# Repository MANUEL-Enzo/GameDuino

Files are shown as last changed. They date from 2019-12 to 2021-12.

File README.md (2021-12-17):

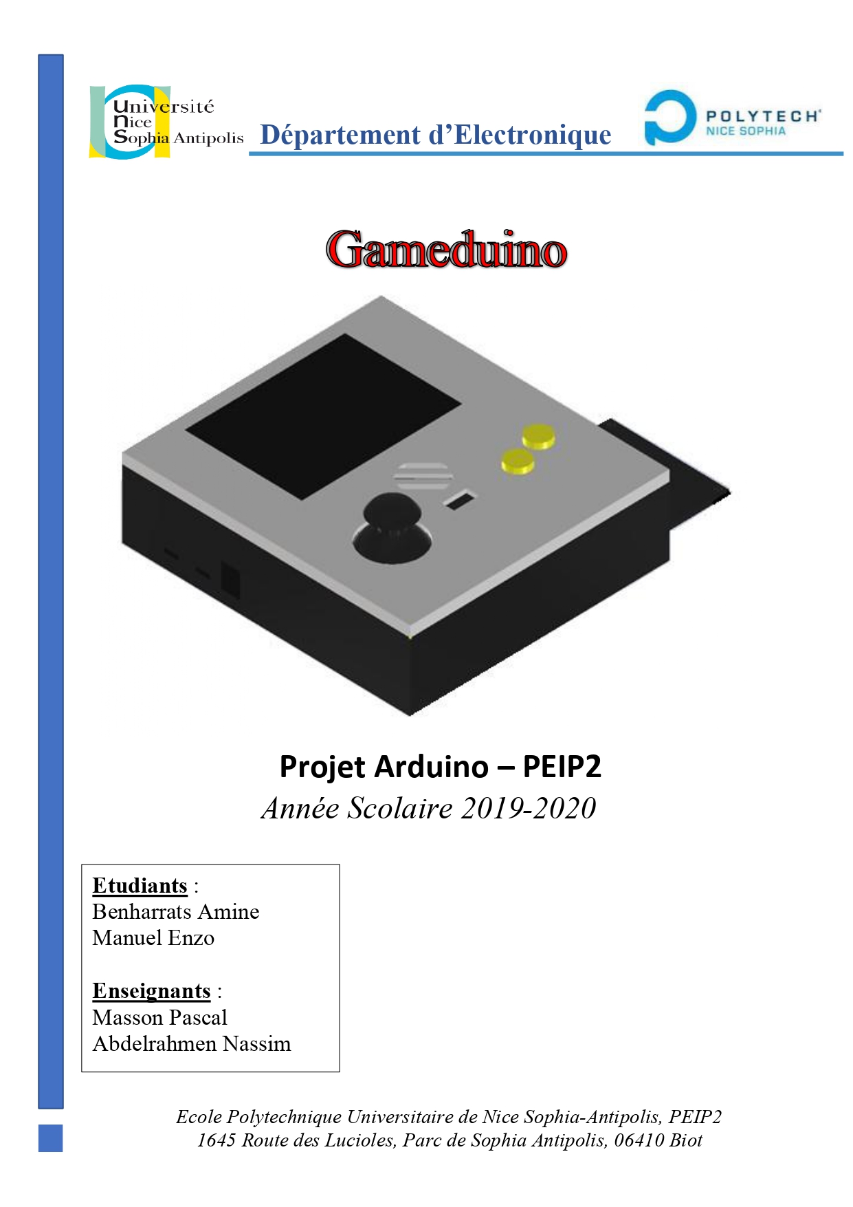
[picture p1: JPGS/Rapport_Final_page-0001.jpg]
Rapport

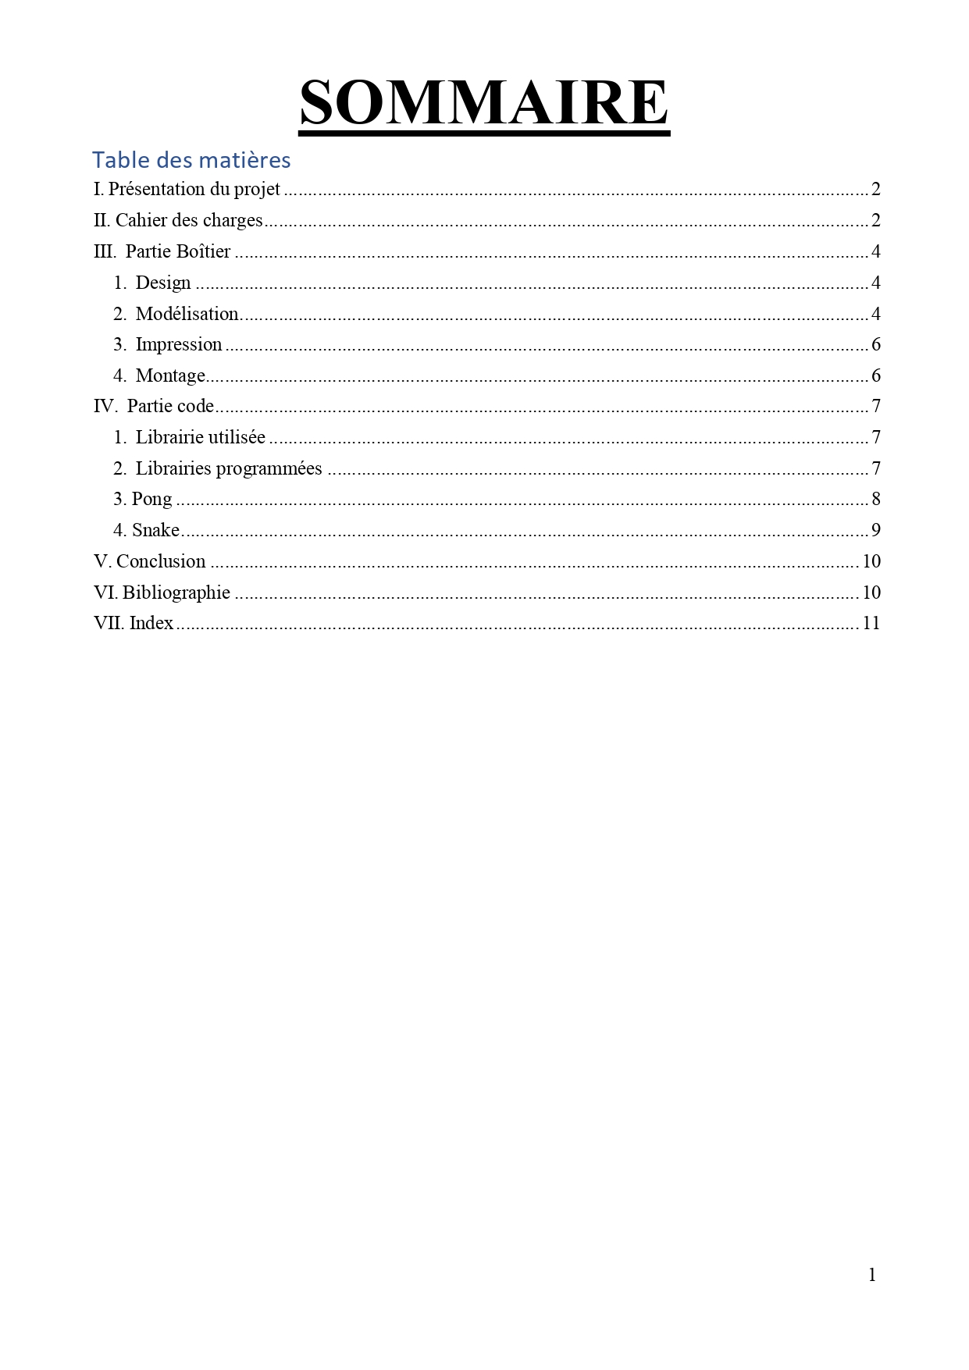
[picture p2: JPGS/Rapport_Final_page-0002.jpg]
Rapport

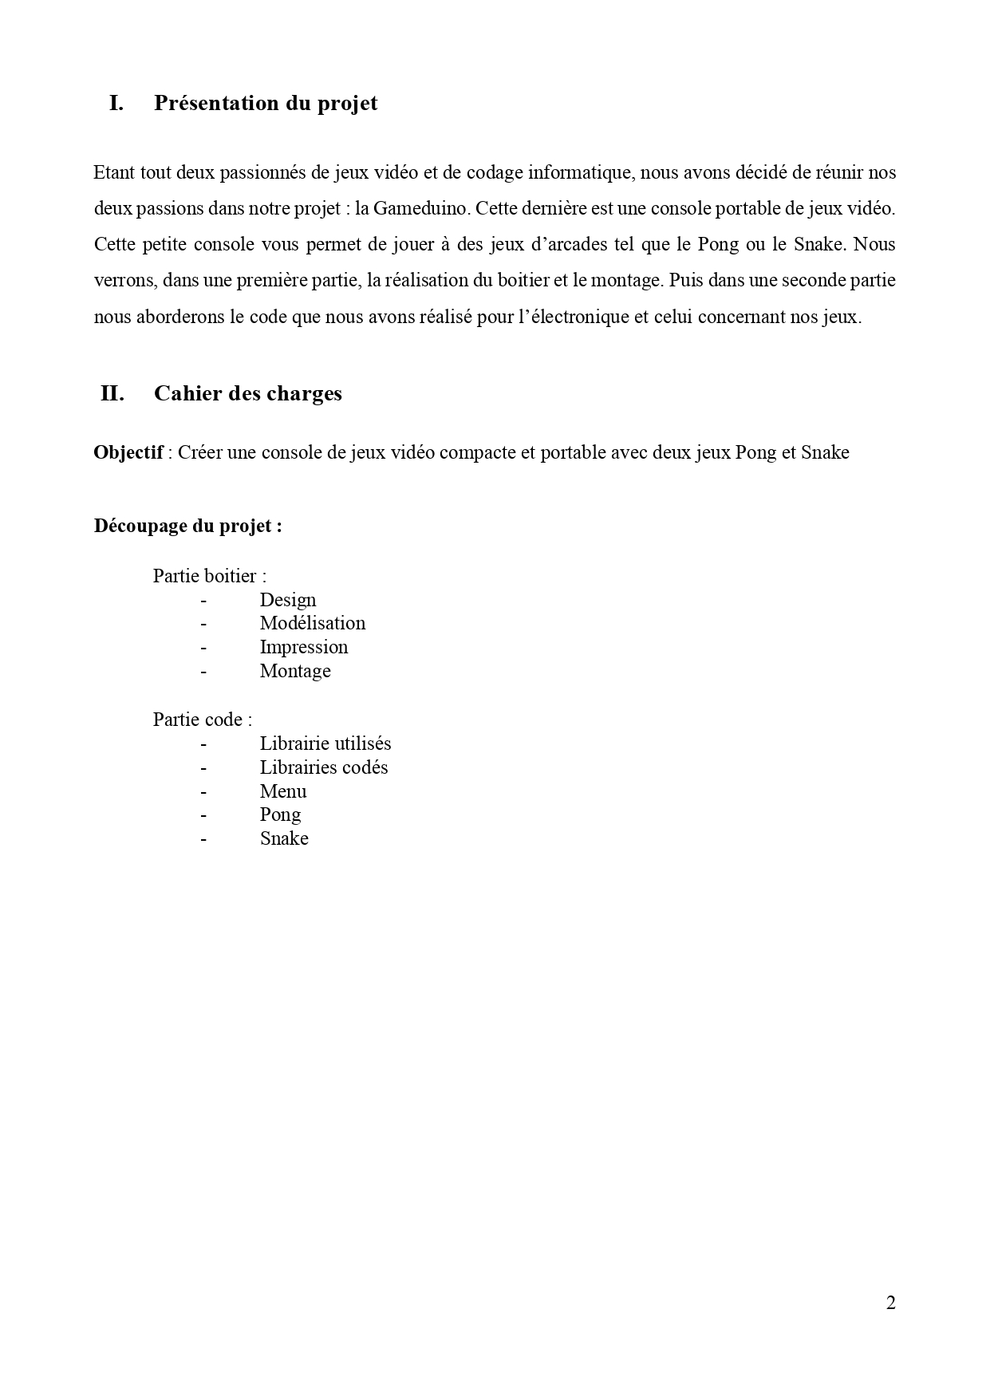
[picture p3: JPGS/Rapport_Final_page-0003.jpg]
Rapport

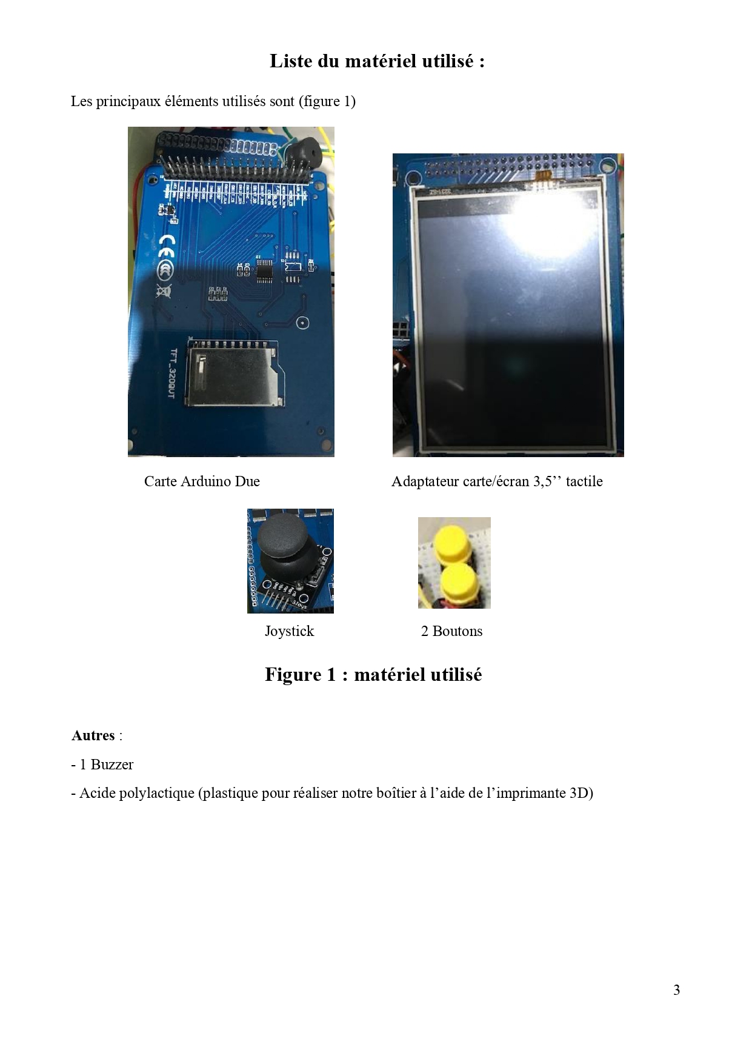
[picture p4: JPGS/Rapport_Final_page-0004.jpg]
Rapport

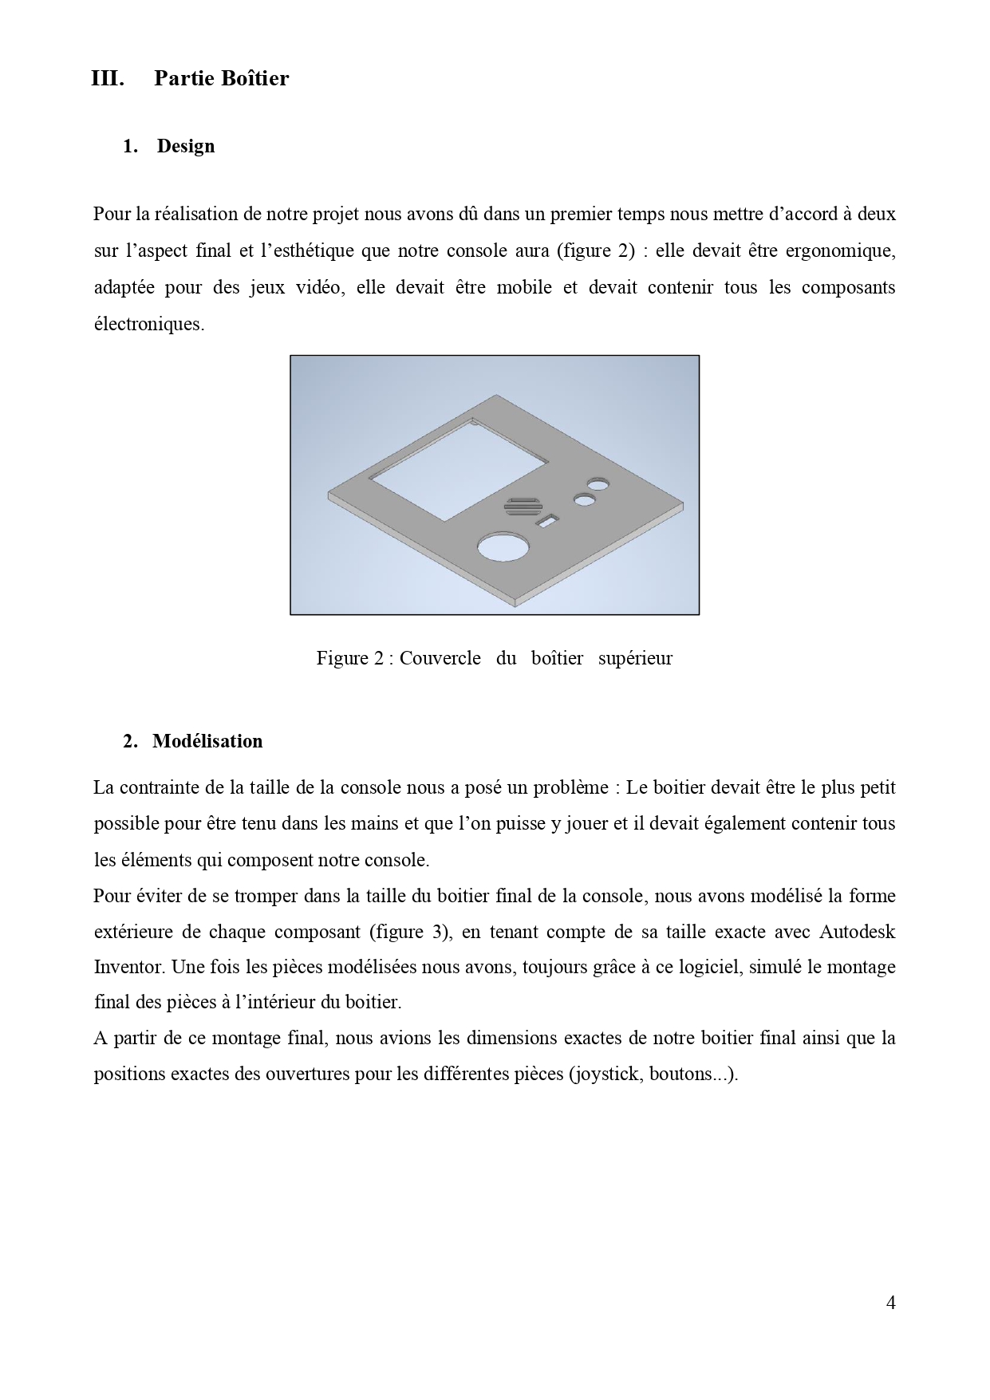
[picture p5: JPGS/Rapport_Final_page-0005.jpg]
Rapport

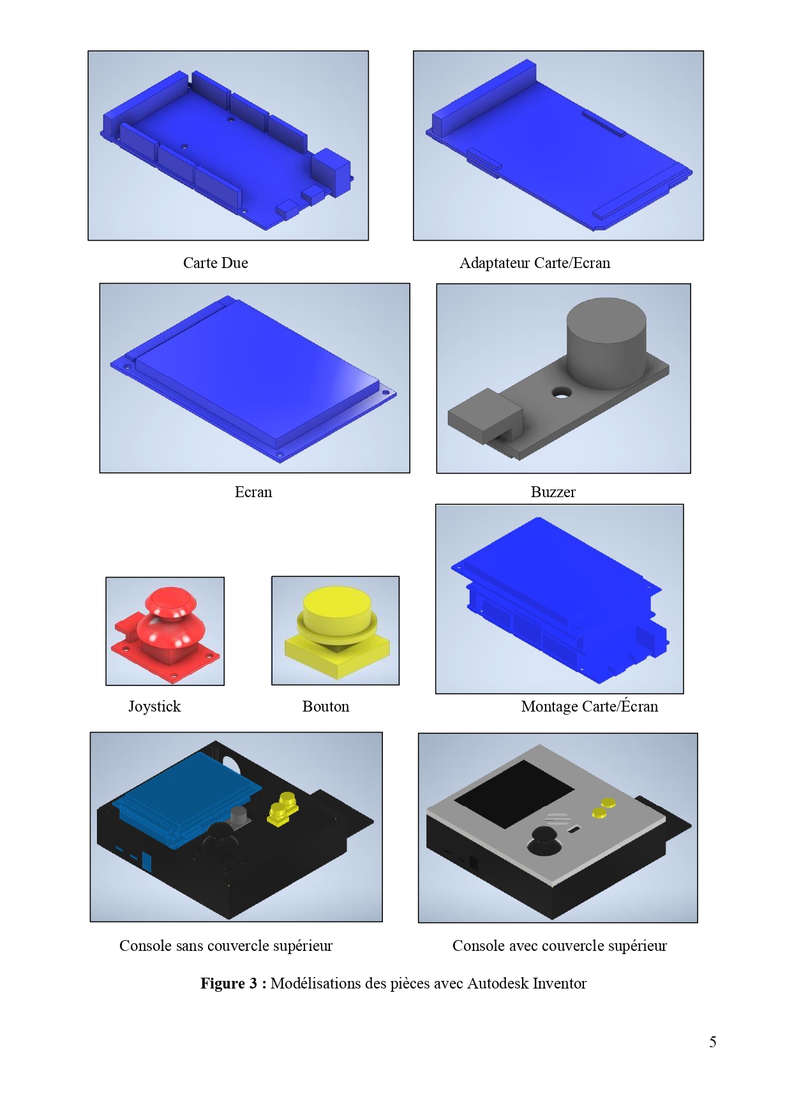
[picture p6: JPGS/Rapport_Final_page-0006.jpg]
Rapport

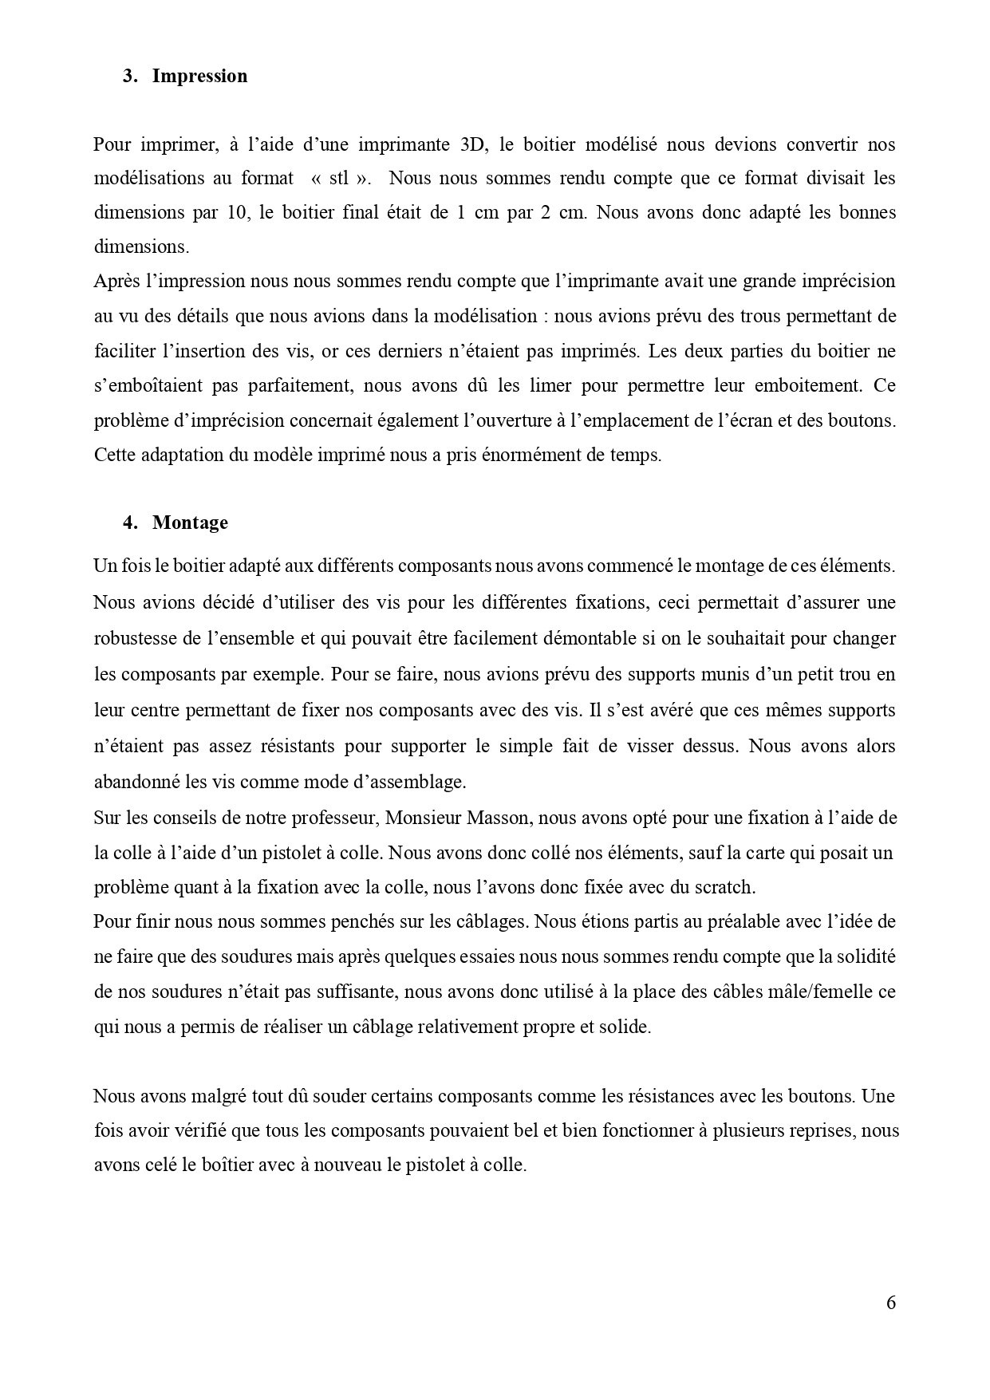
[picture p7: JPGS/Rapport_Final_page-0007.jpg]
Rapport

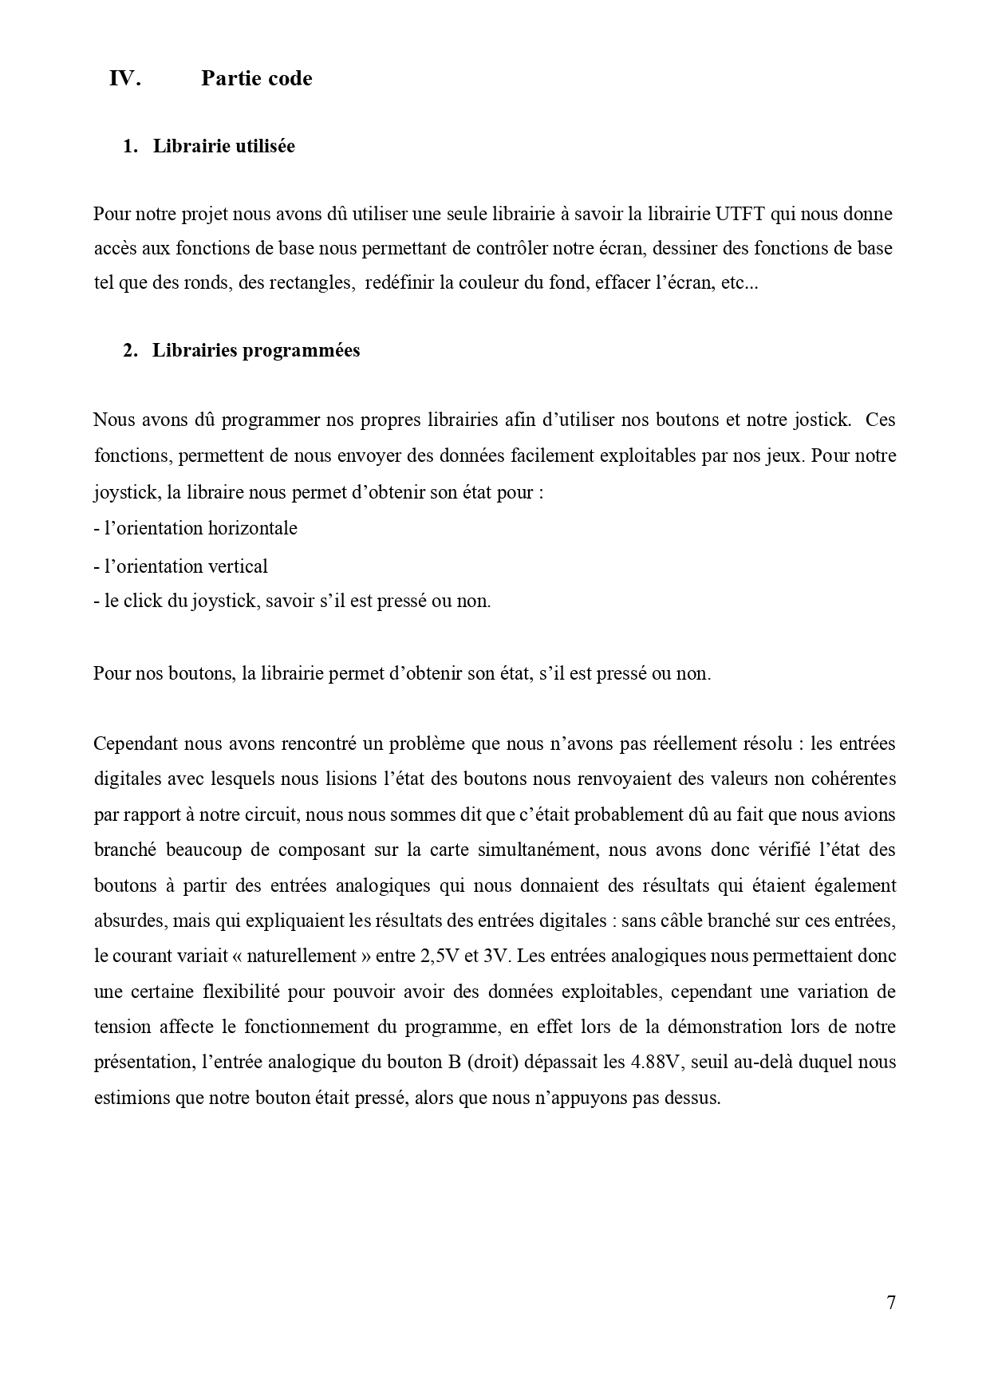
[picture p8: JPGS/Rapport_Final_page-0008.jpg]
Rapport

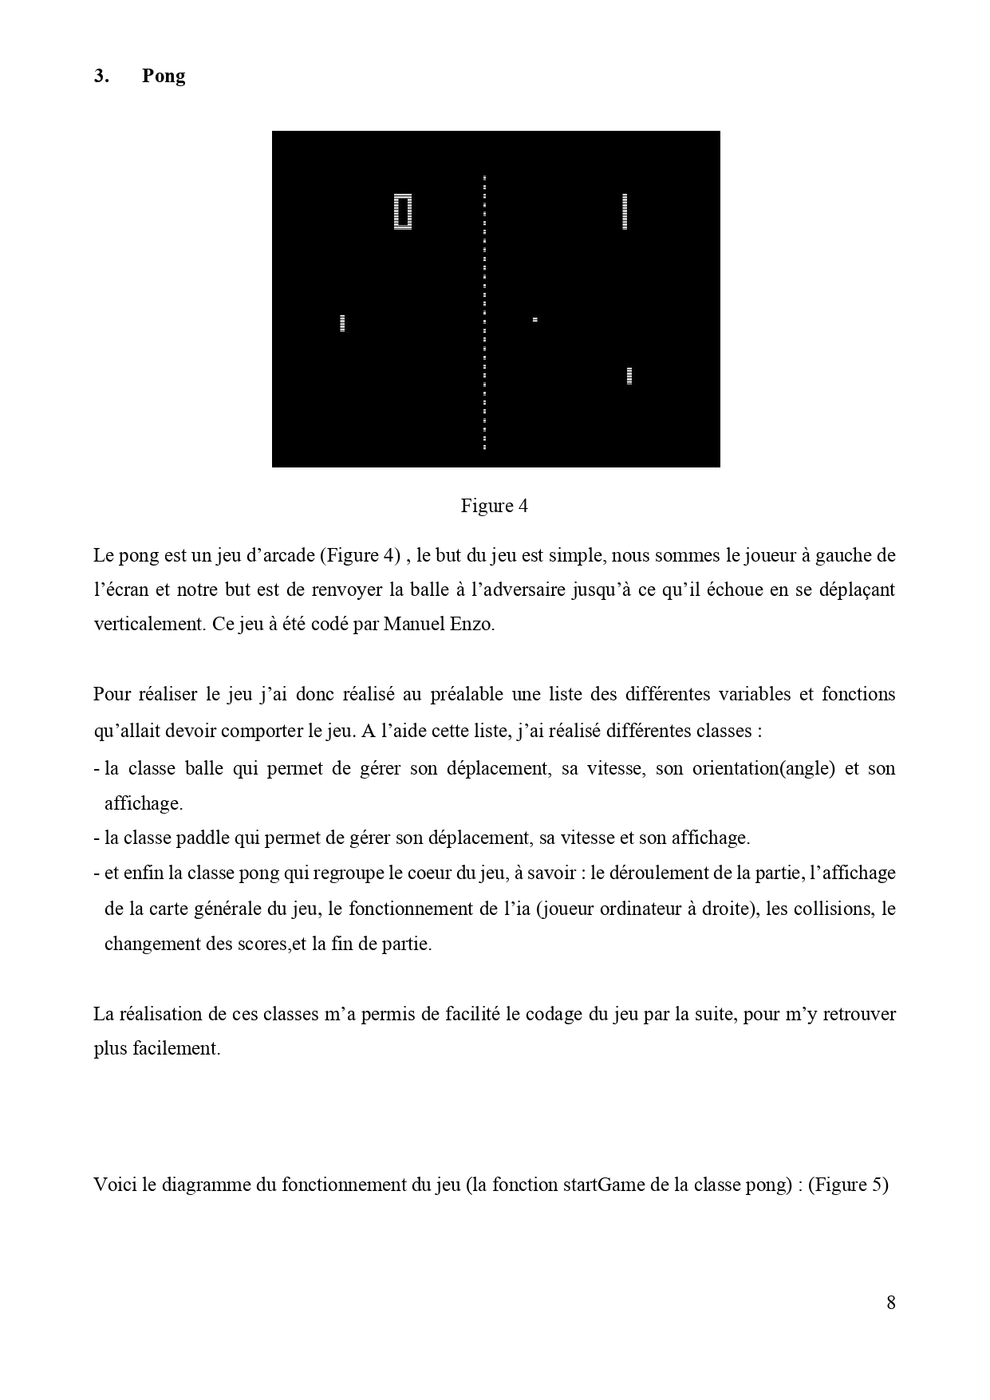
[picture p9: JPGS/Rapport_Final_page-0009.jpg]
Rapport

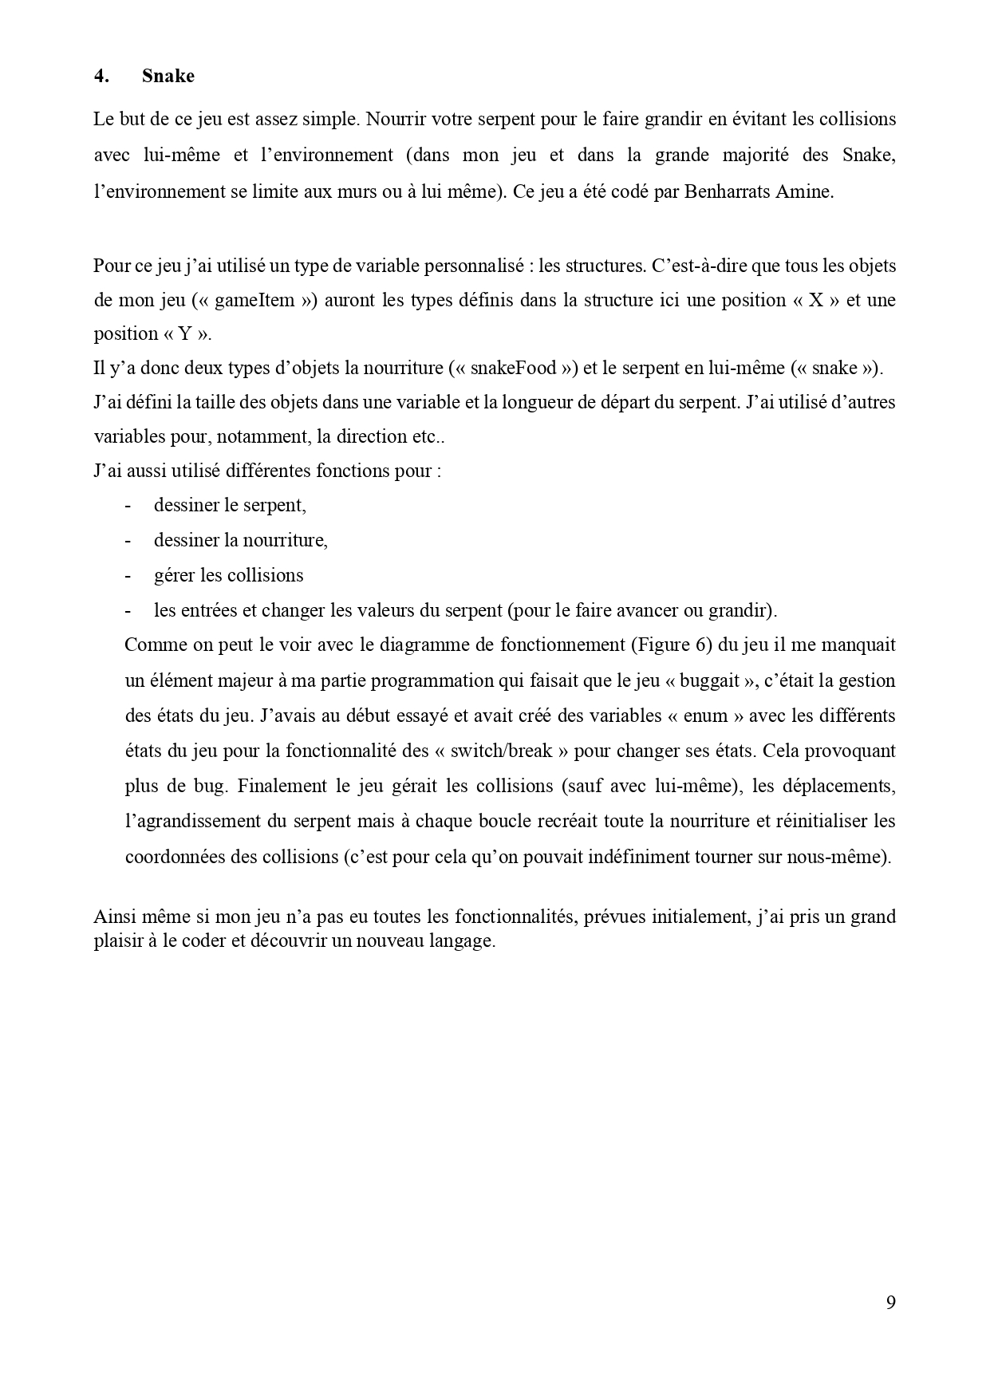
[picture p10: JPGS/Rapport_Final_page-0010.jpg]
Rapport

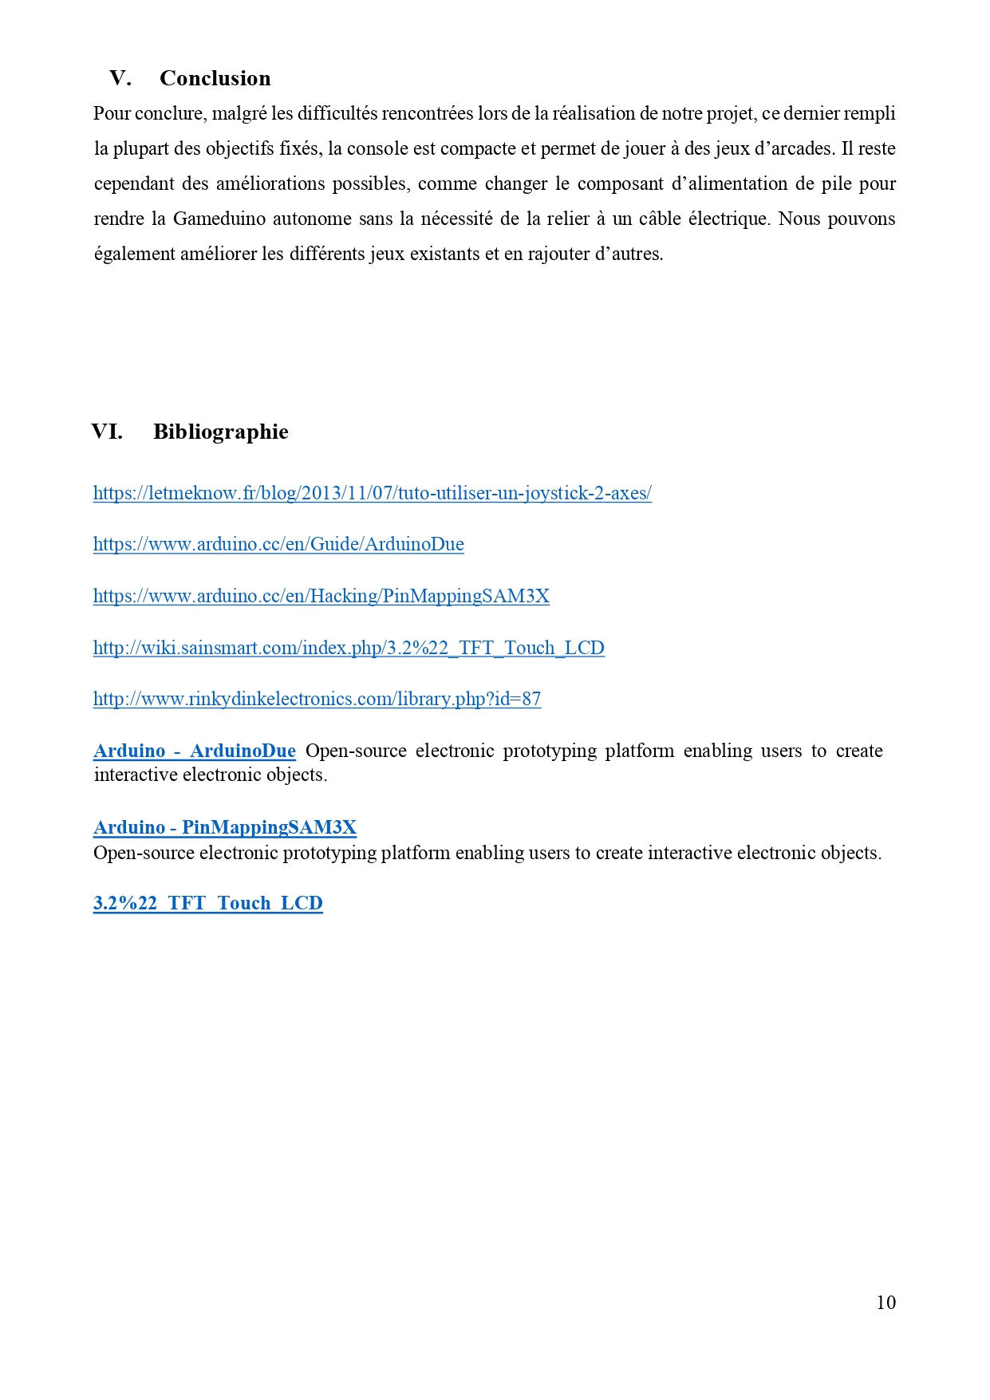
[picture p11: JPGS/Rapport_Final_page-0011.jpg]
Rapport

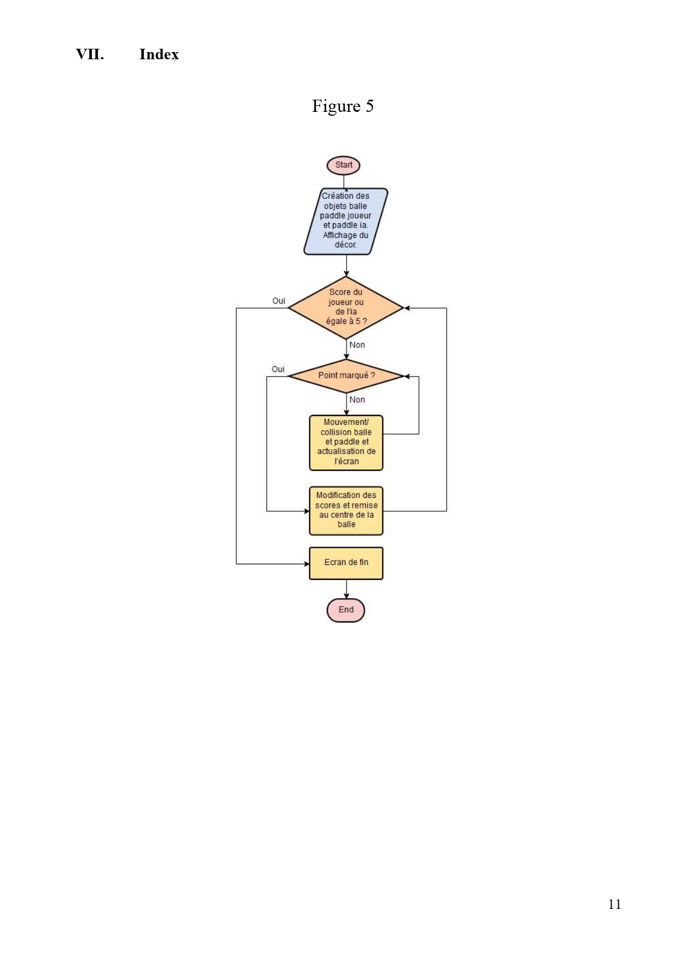
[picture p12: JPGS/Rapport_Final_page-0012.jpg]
Rapport

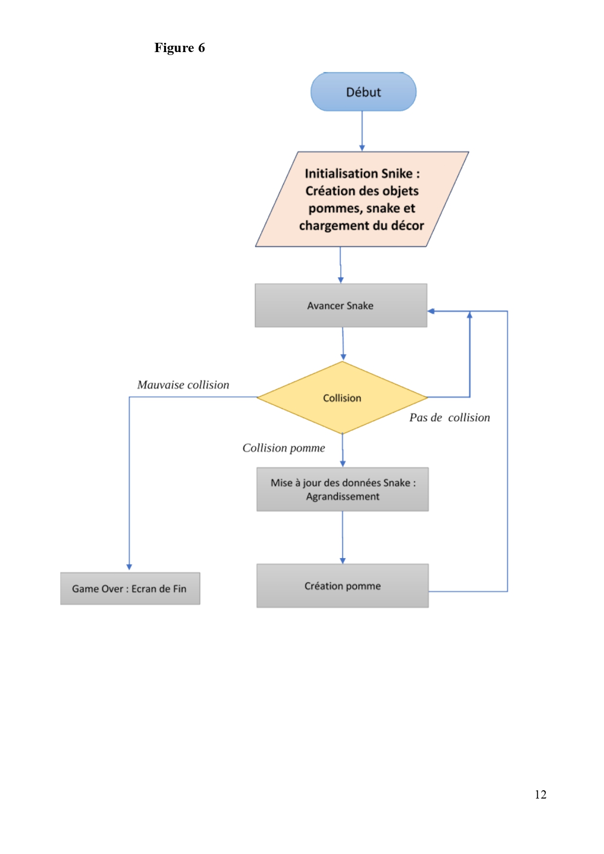
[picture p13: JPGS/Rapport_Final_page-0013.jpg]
Rapport


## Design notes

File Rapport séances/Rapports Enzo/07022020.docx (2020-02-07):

Compte-rendu du 07/02/2020:

- J’ai fini la modélisation du boitier : j’ai fait une place pour la pile et l’interrupteur ON/OFF. J’ai fait les fixations pour le joystick ainsi que le buzzer, et j’ai mis le fond du boitier à niveau pour pouvoir coller les boutons à la bonne hauteur.

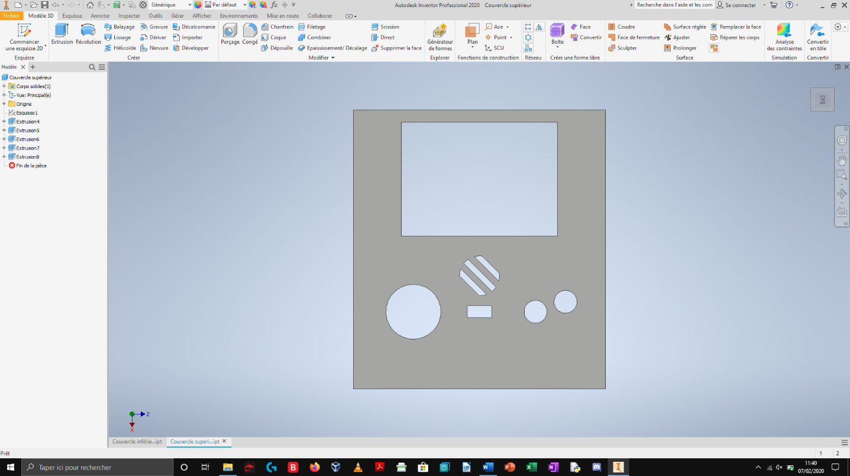
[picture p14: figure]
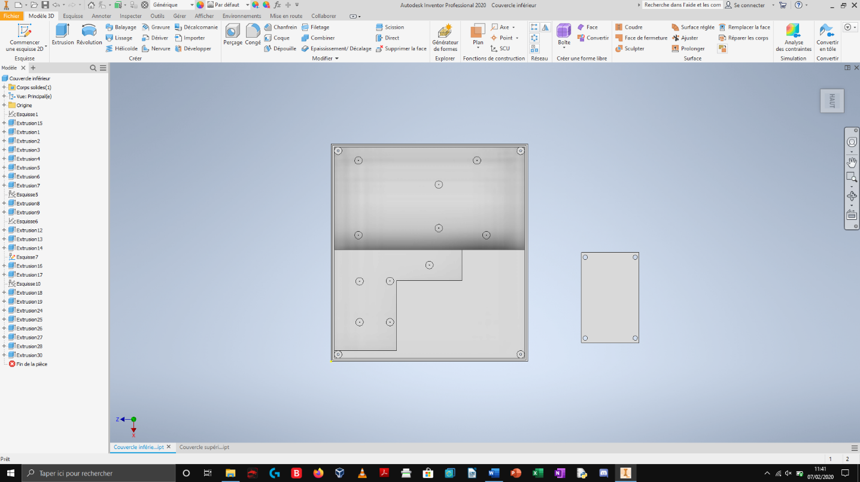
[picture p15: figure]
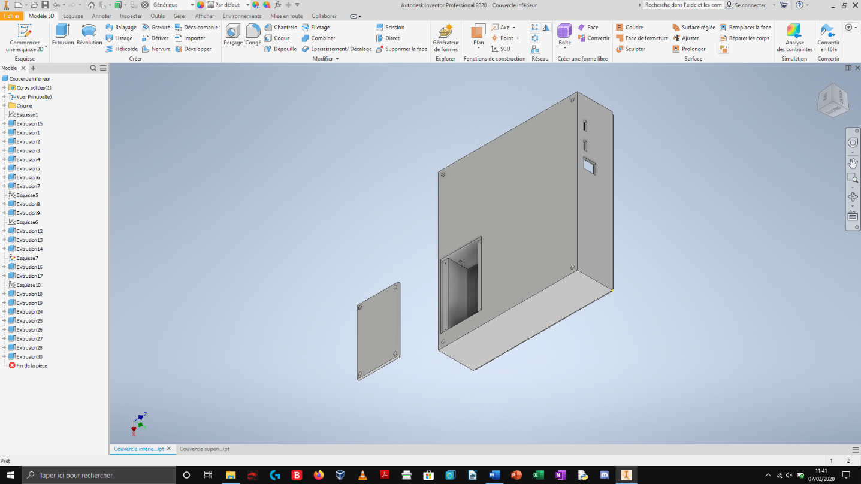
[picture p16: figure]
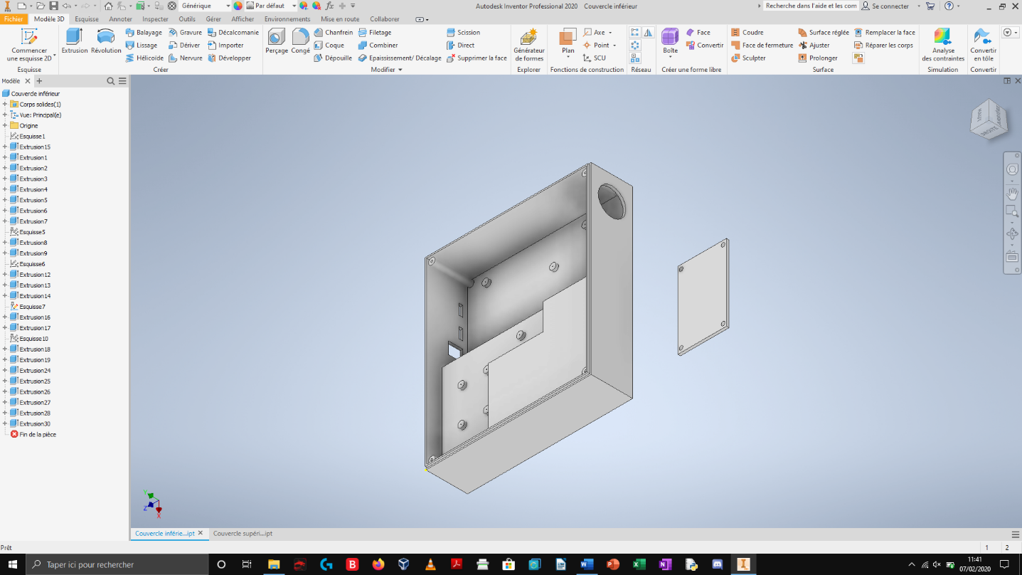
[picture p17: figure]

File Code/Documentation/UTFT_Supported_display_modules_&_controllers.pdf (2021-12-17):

http://www.RinkyDinkElectronics.com/ | (C)2018 Rinky-Dink Electronics, Henning Karlsen

# UTFT

# Multi-Platform Universal TFT display library

# Supported display modules & TFT Controllers

These display modules have been tested, and works with the UTFT library. Please note that vendors/manufacturers may have changed the display modules since I got my test module so there are no guarantees. It should also be noted that not all displays have been tested on all development boards. Compatibility with development boards is tested

with a random selection of displays.

## Other modules may work as long as they have one of the supported controllers (see the

section marked important above).

## The displays marked as shields below have only been tested on platforms where they plug directly in (i.e. on standard “Arduino” form factor development boards.)

Supplier: | ITead Studio
Website: | http://imall.iteadstudio.com/
Module | Model for UTFT() | Controller | Notes | Module | Shield
ITDB02-1.8SP | ITDB18SP | ST7735 | |
ITDB02-2.2 | ITDB22 | HX8340-B(T) | |
ITDB02-2.4E | ITDB24E_8 | S6D1121 | 8bit mode |
ITDB02-2.4E | ITDB24E_16 | S6D1121 | 16bit mode |
ITDB02-2.4E V2 | ITDB24E_V2_8 | ILI9341 | 8bit mode |
ITDB02-2.4E V2 | ITDB24E_V2_16 | ILI9341 | 16bit mode |
2.4” Touch Shield V2 | ITDB24E_V2_8 | ILI9341 | Only tested on Arduino Uno | |
ITDB02-2.8 | ITDB28 | ILI9325D | 8bit version only |
ITDB02-2.8 V2 | ITDB28_V2 / ITDB28_V2_ALT | ILI9341 | See footnote¹ |
2.8” Touch Shield V2 | ITDB28_V2 | ILI9341 | Only tested on Arduino Uno | |
ITDB02-3.2S | ITDB32S | SSD1289 | |
ITDB02-3.2S V2 | ITDB32S_V2 | ILI9341 | |
ITDB02-3.2WD | ITDB32WD | HX8352-A | |
3.2” Touch Shield V2 | ITDB32S_V2 | ILI9341 | Only tested on Arduino Mega/Due | |
ITDB02-4.3 | ITDB43 | SSD1963 | |
ITDB02-5.0 | ITDB50 | SSD1963 | |
ITDB02-2.2SP | ITDB22SP | HX8340-B(N) | Retired |
ITDB02-2.4 | ITDB24 | ILI9325C | Retired |
ITDB02-2.4D | ITDB24D | ILI9325D | Retired |
ITDB02-2.4DWOT | ITDB24DWOT | ILI9325D | Retired |
ITDB02-2.5H | ITDB25H | S1D19122 | Retired |
ITDB02-3.2 | ITDB32 | HX8347-A | Retired |
ITDB02-3.2WC | ITDB32WC | ILI9327 | Retired |
Supplier: | NKC Electronics
Website: | http://store.nkcelectronics.com/
Module | Model for UTFT() | Controller | Notes | Module | Shield
RGB LCD 65K color module | LPH9135 | PCF8833 | | |
Supplier: | Electronics Lee
Website: | http://stores.ebay.com/electronics-lee
Module | Model for UTFT() | Controller | Notes | Module | Shield
3.2” TFT LCD Arduino Shield - Revision A | ELEE32_REVA² | SSD1289 | Uses 16bit latched mode³ Not supported on chipKit or Arduino Due | |
Shield - Revision B 3.2” TFT LCD Arduino | ELEE32_REVB | SSD1289 | 8bit mode⁴ Not supported on chipKit or Arduino Due | |

1 It seems like some modules are 16bit even though they are marked as 8bit. Use ITDB28_V2_ALT for those modules. 2 Changed from INFINIT32 3 Use UTFT myGLCD(ELEE32_REVA,A1,A2,A0,A3,A5); to initialize 4 Use UTFT myGLCD(ELEE32_REVB,A1,A2,A0,99); to initialize

# IMPORTANT:

## Please note that any attempt to use this library with display modules that are not on this list is done at your own risk. Using this library with display modules not on this list may work just fine, but there is also a tiny, tiny risk that it may damage

your display module and/or development board. Consider yourself warned.

## Do not ask me if a display module that is not on this list will work with the library. As I have not tested it I simply do not know. You will just have to try for

yourself (at your own risk).

## If your exact display module/shield is not on this list, or you have bought it from another vendor than the one listed as the supplier, you will have to direct any

questions to your vendor. I cannot answer them.

## There is also no point in sending me code that will make display modules/shields not on this list work with the library. I only add support for new display modules and

shields at the request from vendors and manufacturers.

Supplier: | Coldtears Electronics
Website: | http://stores.ebay.com/coldtears-electronics-store
Module | Model for UTFT() | Controller | Notes | Module | Shield
2.2" TFT LCD Module | CTE22 | S6D0164 | Basic support only⁵ |
2.8" TFT LCD Module | CTE28 | ILI9325D | Basic support only⁵ |
3.2" TFT LCD Module (R2) | CTE32_R2 | ILI9341 | Basic support only⁵ |
3.2" HR TFT LCD Module | CTE32HR | ILI9481 | Basic support only⁵ |
3.2" Wide TFT LCD Module | CTE32W | HX8352-A | Basic support only⁵ |
3.5” IPS TFT LCD Module | CTE35IPS | R61581 | Basic support only⁵ |
4.0” TFT LCD Module | CTE40 | ILI9486 | Basic support only⁵ |
5.0" TFT LCD Module | CTE50 | SSD1963 | Basic support only⁵ |
5.0" CPLD TFT LCD Module | CTE50CPLD | CPLD⁶ | |
7.0" TFT LCD Module | CTE70 | SSD1963 | Basic support only⁵ |
7.0" CPLD TFT LCD Module | CTE70CPLD | CPLD⁶ | |
3.2" TFT LCD Module | CTE32 | SSD1289 | Retired |
Supplier: | Watterott electronic
Website: | http://www.watterott.com/
Module | Model for UTFT() | Controller | Notes | Module | Shield
MI0283QT-9A | MI0283QT9 | ILI9341 | Only tested on Arduino Uno |
Supplier: | ElecHouse
Website: | http://www.elechouse.com/
Module | Model for UTFT() | Controller | Notes | Module | Shield
5.0" TFT LCD Module | EHOUSE50 | SSD1963 | |
5.0" CPLD TFT LCD Module | EHOUSE50CPLD | CPLD⁶ | |
7.0" TFT LCD Module | EHOUSE70 | SSD1963 | |
Supplier: | DisplayModule
Website: | http://www.displaymodule.com/
Module | Model for UTFT() | Controller | Notes | Module | Shield
DM-TFT18-101 | DMTFT18101 | HX8353C | |
DM-TFT22-102 | DMTFT22102 | S6D0164 | |
DM-TFT24-104 | DMTFT24104 | ILI9325D | |
DM-TFT28-103 | DMTFT28103 | ILI9325D | |
DM-TFT28-105 | DMTFT28105 | ILI9341 | Incompatible with chipKit | |

5 UTFT does not make use of the on-board Font and Icon Flash chip. 6 CPLD modules are currently not compatible with chipKit.

## If you are unsure which module you have you can try these model codes for the supported controllers instead:

Controller | Model for UTFT() | Supported mode
8bit | 16bit | Serial
CPLD | CPLD | |
HX8340-B(T) | HX8340B_8 |
HX8352-A | HX8352A | |
HX8353-C | HX8353C |
ILI9325D | ILI9325D_8 |
| ILI9325D_16 | |
| ILI9325D_16ALT⁷ | |
ILI9341 | ILI9341_S4P⁸ | | |
| ILI9341_S5P⁹ | | |
| ILI9341_8 |
| ILI9341_16 | |
ILI9481 | ILI9481 | |
ILI9486 | ILI9486 | |
PCF8833 | PCF8833 | | |
R61581 | R61581 | |
S6D0164 | S6D0164 |
S6D1121 | S6D1121_8 |
| S6D1121_16 | |
SSD1289 | SSD1289 | |
| SSD1289_8 |
| SSD1289LATCHED¹⁰ | | LATCHED
SSD1963 | SSD1963_480 | |
| SSD1963_800 | |
| SSD1963_800ALT¹¹ | |
ST7735 | ST7735 | | |

## The following TFT controllers are used by display modules and shields that have been retired. They are still supported but support may be removed in future versions of the library. These controllers are disabled by default to save flash memory. To use them

you must enable support for them in “memorysaver.h”.
Controller | Model for UTFT() | Supported mode
8bit | 16bit | Serial
HX8340-B(N) | HX8340B_S | | |
HX8347-A | HX8347A | |
ILI9325C | ILI9325C |
ILI9327 | ILI9327 | |
S1D19122 | S1D19122 | |

7 Alternative initialization for some 2.8” display modules 8 Use this for 4 Pin serial modules 9 Use this for 5 Pin serial modules 10 Currently only supported on 5v Arduino board, and not on chipKit or Arduino Due 11 Alternative initialization for 7” displays

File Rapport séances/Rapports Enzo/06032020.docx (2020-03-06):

Compte-rendu du 06/03/2020;

Nous avons dans un premier temps essayer de souder nos câbles à nos boutons, buzzer et notre joystick, puis nous avons opté pour des câbles male-femelle. Nous avons soudé nos résistances à nos boutons pour réaliser le circuit nécessaire au fonctionnement de nos boutons. Nous avons collé la carte au fond du boitier, puis l’écran sur le couvercle supérieur, ainsi que le joystick, les boutons et le buzzer dans le boitier inférieur.

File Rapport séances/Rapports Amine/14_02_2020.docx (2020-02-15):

Rapport de séance 14/02/2020

Cette séance nous avons reçu l’impression de la base de notre gameboy et son « couvercle ». Mais l’impression n’était pas parfaite il a donc fallu trouver des solutions.

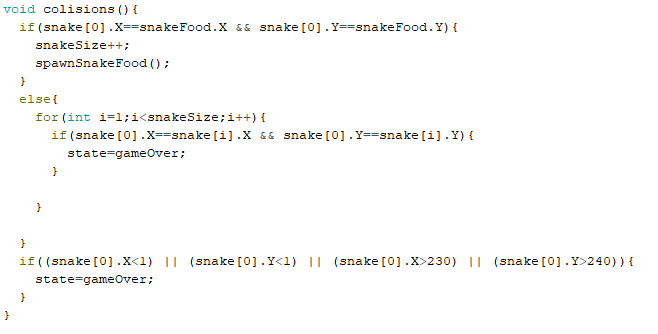
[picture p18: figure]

J’ai cherché quelque solution, mais je me suis quand même plus concentré sur mon code où j’ai fini le système de collision que j’avais commencé à la dernière séance. Ce qui m’a pris le plus de temps est comment « augmenter » la taille du serpent à chaque fois qu’il mange un boost.

Il faut aussi que je règle un problème d’affichage sur notre écran lors du lancement du jeu*

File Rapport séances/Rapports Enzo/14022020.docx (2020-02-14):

Compte rendu : 14/02/2020

J’ai passé ma séance à ajuster l’impression du boitier avec les pièces pour qu’elles rentrent correctement. J’ai compris également que la solution de visser les éléments n’était pas la bonne, je vais donc les coller directement au boitier. Cependant on va réimprimer le couvercle supérieur, car il manque environ 1 mm de matière en hauteur ce que fait que les mesures ne sont pas correctement respectées.

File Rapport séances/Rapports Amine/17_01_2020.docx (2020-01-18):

Rapport du 17/01/2020

Lors de la dernière séance, j’avais avancé sur mon code plus précisément la liste de toute les méthodes et variables dont j’aurais besoin. Mais je me suis vite aperçu que Notepad++ était, certes un bon éditeur de code, mais rien qu’avec mes premières librairies la gestion et l’organisation du projet étaient chaotique. Ainsi, lors de cette séance nous avons chercher un logiciel permettant une meilleure gestion du projet (et de nos codes surtout pour le long termes). Ayant déjà installer Eclipse pour nos cours de Java, on s’est aperçu qu’il existait aussi un package pour le développement en c++, et Eclipse nous proposait même la création d’un projet Arduino. Ainsi lorsque l’on crée une nouvelle classe, l’éditeur crée automatiquement les fichiers « .h » et « .cpp » ce qui nous facilité la tâche et nous permettait un gain de temps mais il nous montré aussi toute les classes déjà crée, leurs relations, leurs affections etc…

Par la suite nous avons finit l’assemblage de nos pièces pour la modélisation de la gameduino.

Par la suite il a fallu présenter notre projet à nos professeurs, ce qui m’a permis de comprendre que nous étions un peu en retard au niveau du code, j’ai donc opté pour une nouvelle stratégie. Au lieu de m’attaquer directement sur le jeu le plus « dur » niveau code, je vais d’abord faire le jeu snake, pour d’une part bien comprendre la gestion de collision, des listes et de la mémoire en c/c++ sur un jeu plus simple, mais aussi pour avoir un rendu plus avancé (voir même fini) pour la journée porte ouverte qui aura lieu le 6 février et la base du code au niveau de la collision pour le jeu pacman. Ainsi le reste de la séance j’ai rétabli la liste des variables et méthode dont j’ai besoin et avancé sur le code.

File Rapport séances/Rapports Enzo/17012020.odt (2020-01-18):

Rapport 17/01/2020

- Nous avons rechercher et télécharger un logiciel permettant de créer des projets en C++ plus facilement : « Eclipse IDE for C/C++ Developers ». Ce logiciel créer automatiquement les fichiers «*.h » et « *.cpp » lorsque l’on veut rajouter une classe et commencer l’écriture des classes nous faisais gagner un temps considérable.

- Nous avons terminé la modélisation de la gameboy et avons donc un aperçu :

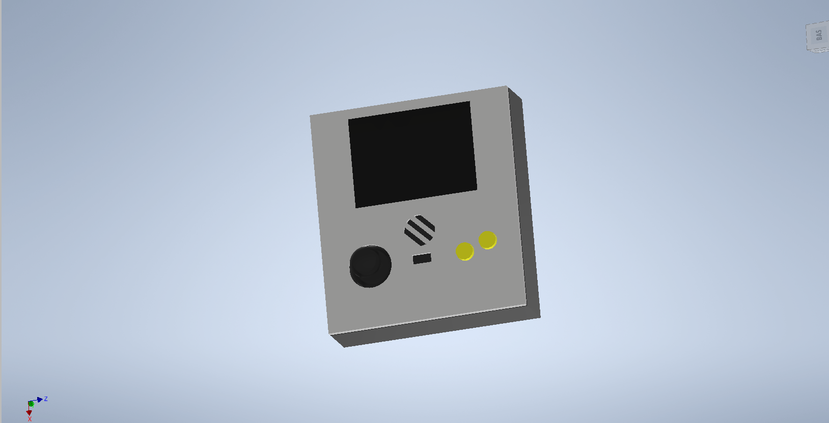
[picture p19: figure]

- Nous avons présenter notre projet à nos professeurs.

- Nous avons commencer à coder les différentes classes de notre jeux. J’ai commencer à rencontrer quelques problèmes concernant le code : comment importer des librairies « élémentaires » pour les calculs de racines ou encore pour choisir un nombre aléatoirement.

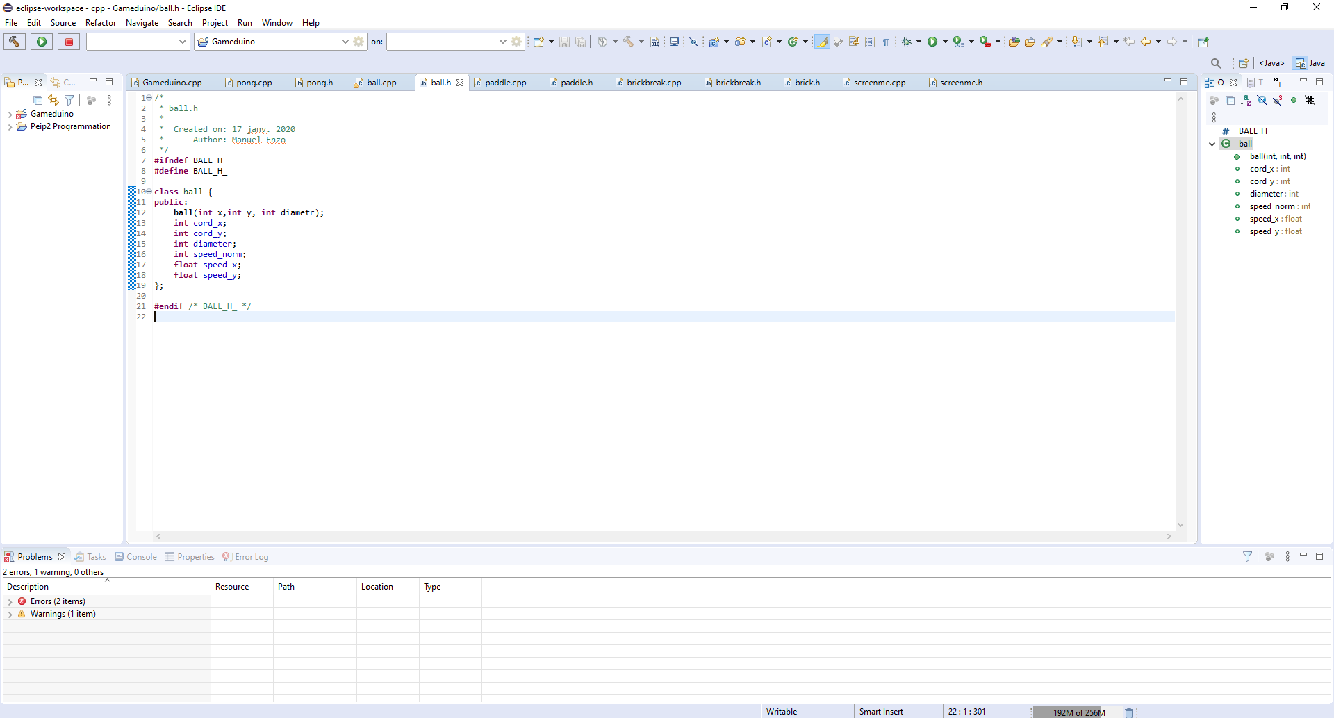
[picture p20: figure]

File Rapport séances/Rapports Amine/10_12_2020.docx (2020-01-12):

Rapport de séance 10/01/2020

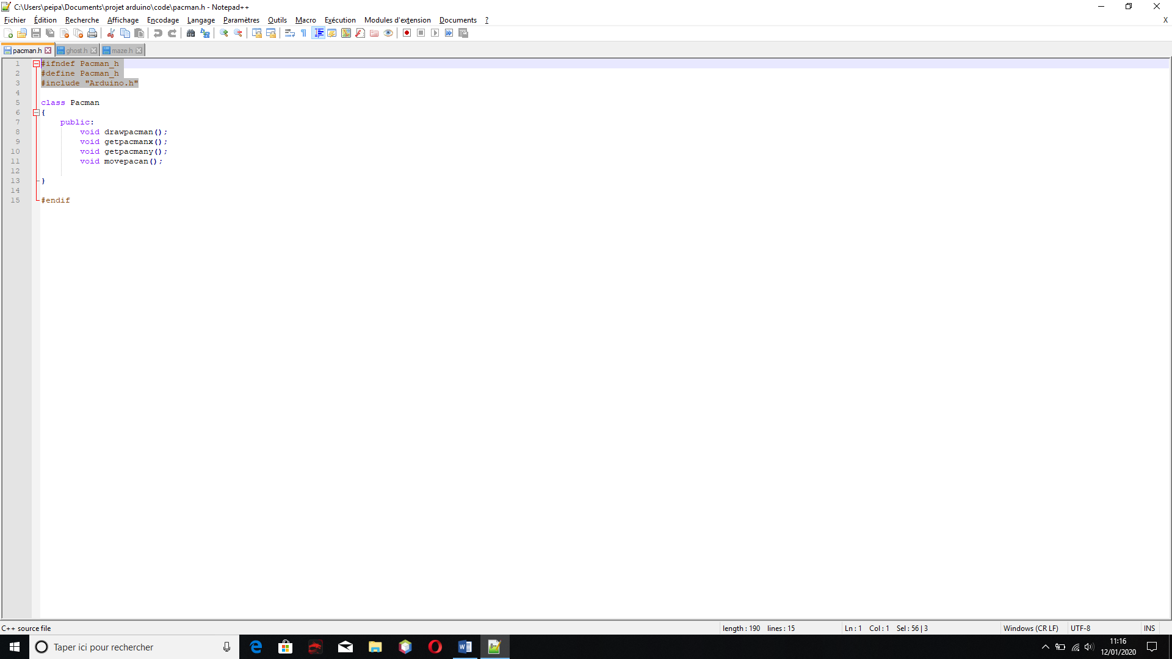
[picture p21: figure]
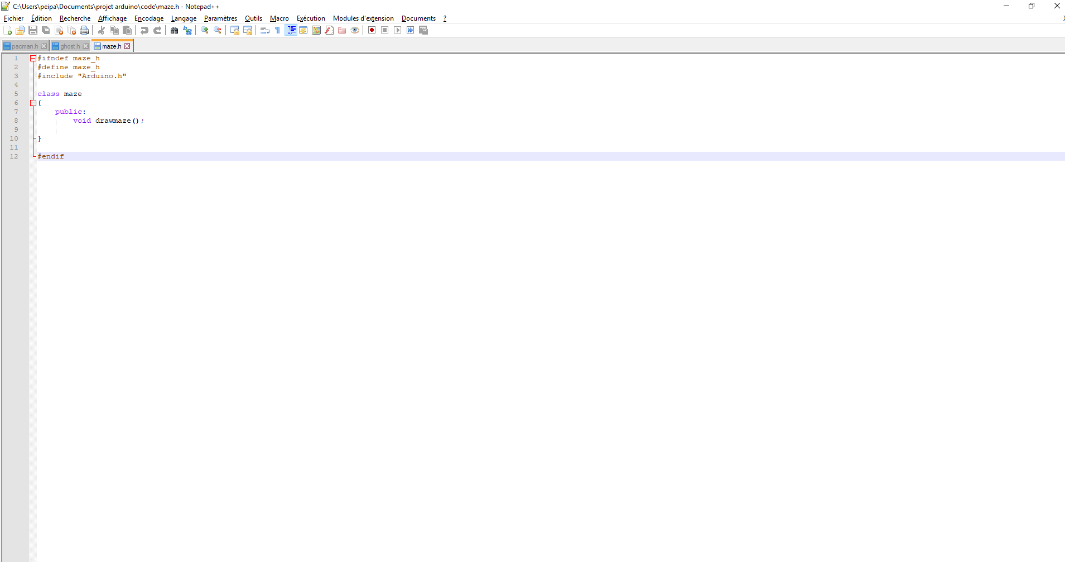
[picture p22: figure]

Il fallait avant, je me lance dans le code de mon jeu, classifier toute les variables, classes, fonctions dont j’ai besoin. Ainsi j’ai fait la liste de toutes les fonctions dont j’avais besoins dans mes fichier « .h ». Dans ces fichiers on définit juste les fonctions/méthodes que j’utiliserai. L’explication informatique de ces méthodes se trouve dans le fichier « .cpp » ou directement sous format arduino « .ino ». Par la suite j’agencerai toute mes librairies en une seule, qui sera la librairie racine de notre projet. J’ai passer beaucoup de temps à comprendre ces notions, puis j’ai du revoir toute la librairie UTFT pour comprendre et bien choisir ce que je pourrais utiliser dedans.

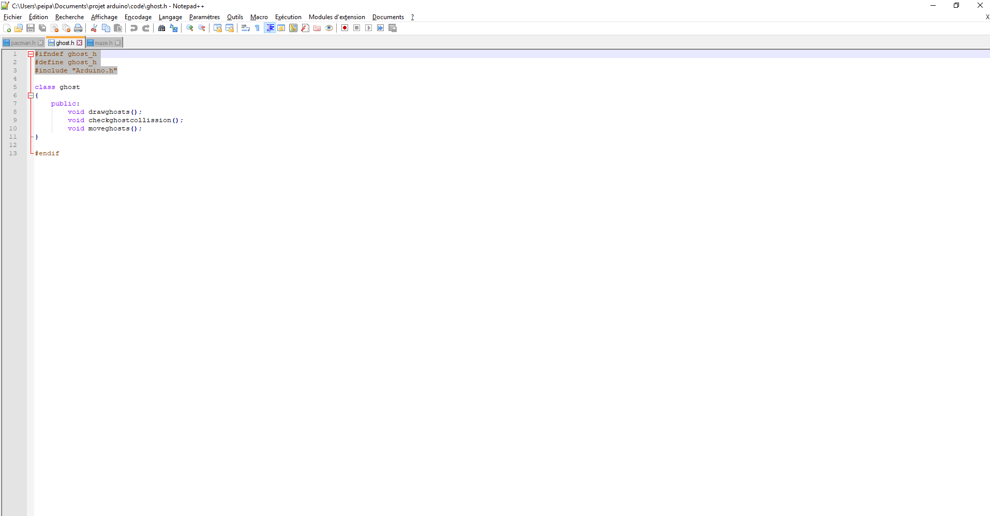
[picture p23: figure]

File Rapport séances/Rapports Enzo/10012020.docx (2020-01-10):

10/01/2020

- Recherche sur internet concernant la programmation des libraires dans le language C++ : comment faire une libraire, comment faire une classe, comment créer un objet dans une autre classe…
- Réalisation d’une liste des classes et des variables nécessaires pour les deux jeux :

pong

{

ball(ball),

paddle_player(player),

paddle_AI(player),

}

ball

{

speed_norm(float),

speed_x(float),

speed_y(float),

cord_x(int),

cord_y(int),

height(int)(%2=1),

}

paddle

{

cord_x(int),

cord_y(int),

height(int)(%2=1),

width(int)(%2=1),

pin_joy_x(int),

pin_joy_y(int),

joy_x(int),

joy_y(int),

}

brick break

{

ball(ball),

paddle_player(paddle),

brick1,brick2,...(brick),

}

screen

{

screen(list of ints),

}

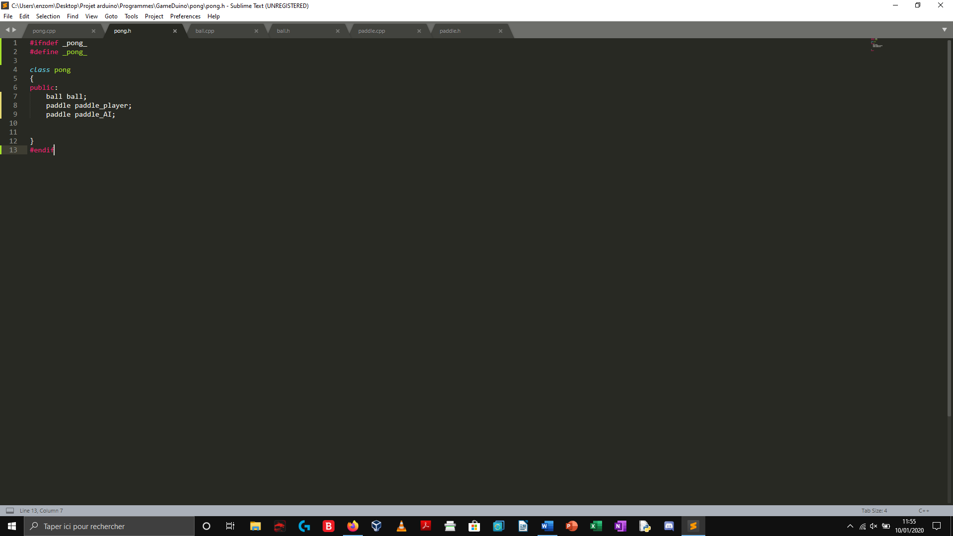
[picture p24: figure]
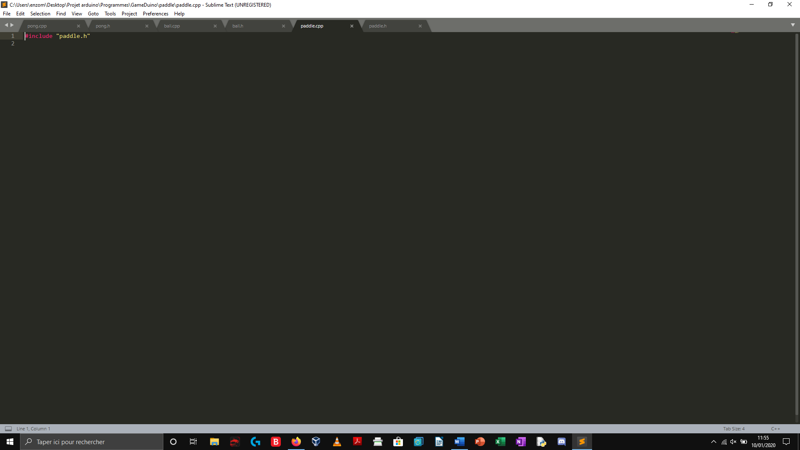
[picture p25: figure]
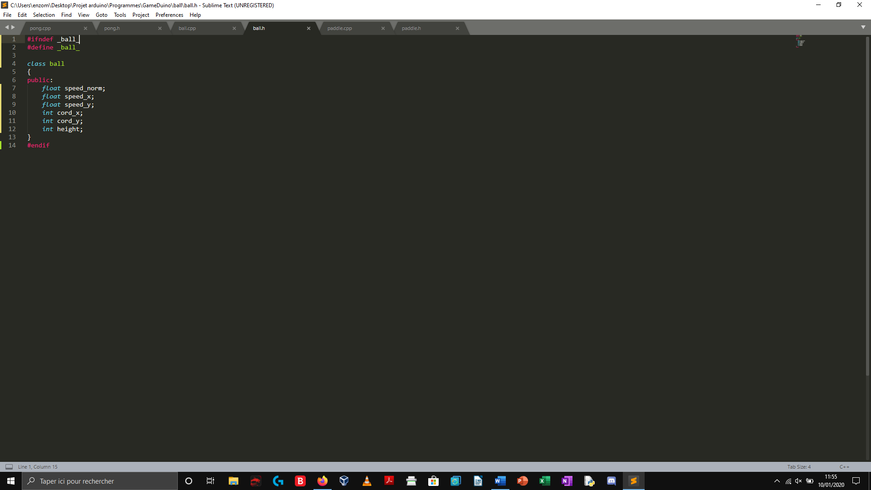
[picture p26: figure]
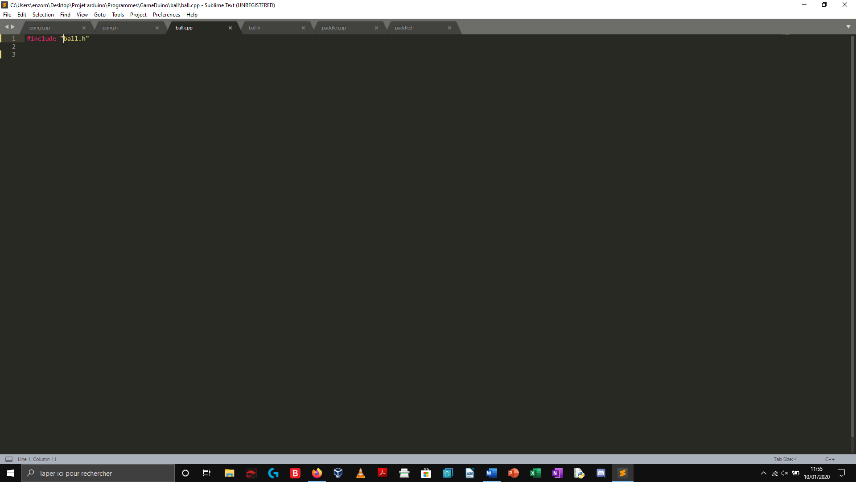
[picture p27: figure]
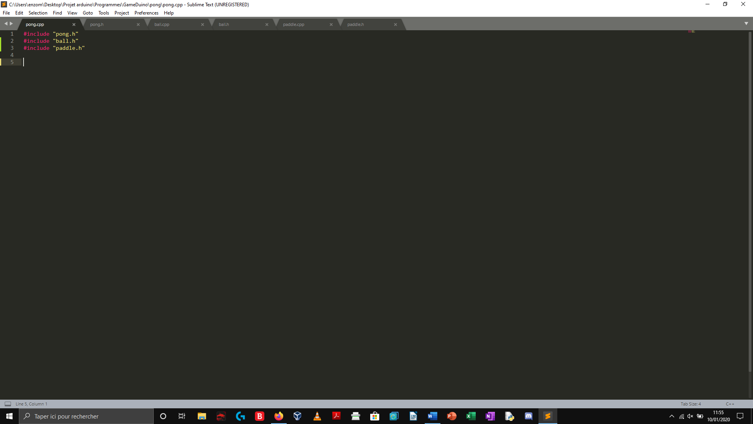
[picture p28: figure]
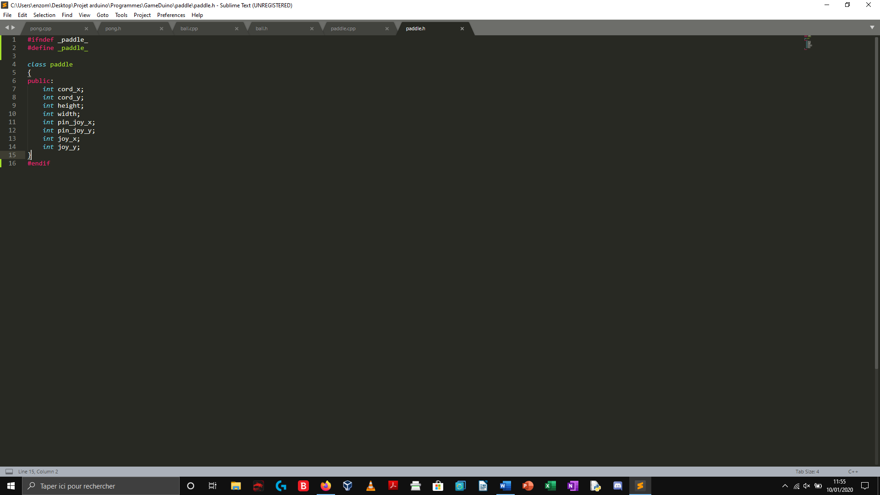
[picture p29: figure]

- Léger avancement dans la modélisation et le moyen de fixer les boutons poussoirs à l’intérieur de la console : possiblement coller les boutons.

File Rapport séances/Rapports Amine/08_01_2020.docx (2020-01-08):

Rapport de Séance du 8 janvier 2020

Après avoir réglé le problème de l’alimentation, la question du fablab restera en suspens toute la séance.

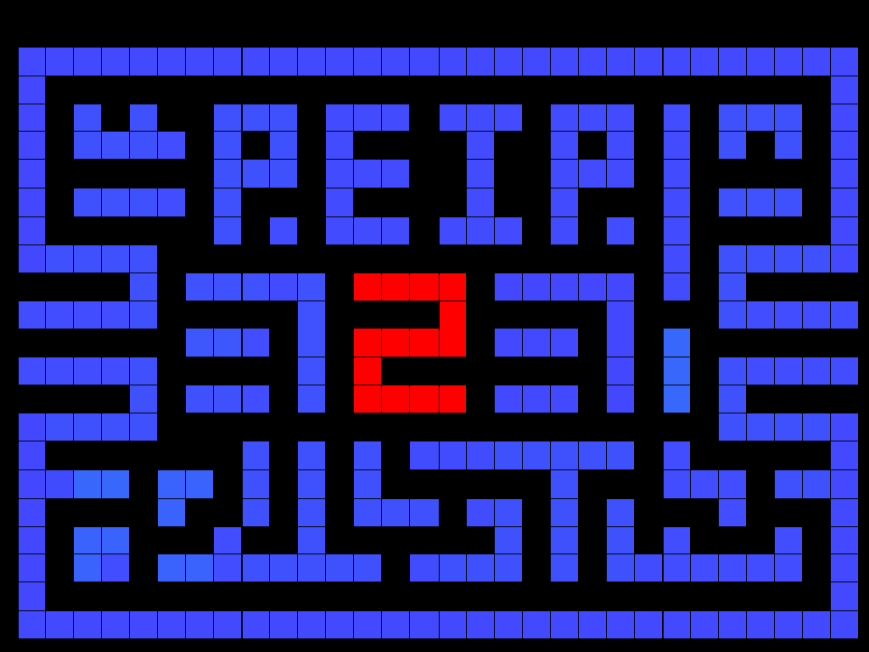
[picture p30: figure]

L’objectif du jour était de chacun modéliser l’aspect graphique de nos jeux respectifs. J’ai tout d’abord commencé par l’aspect graphique de pacman en utilisant le logiciel gimp.

Il reste donc à ajouter le texte (score + vie), que l’on ne pouvait pas ajouter directement sur Gimp. J’ai fait le choix spécifique de prendre le croquis en 32x24, car notre écran est en 320x240 et nous avons préalablement choisis une hitbox de 10px.

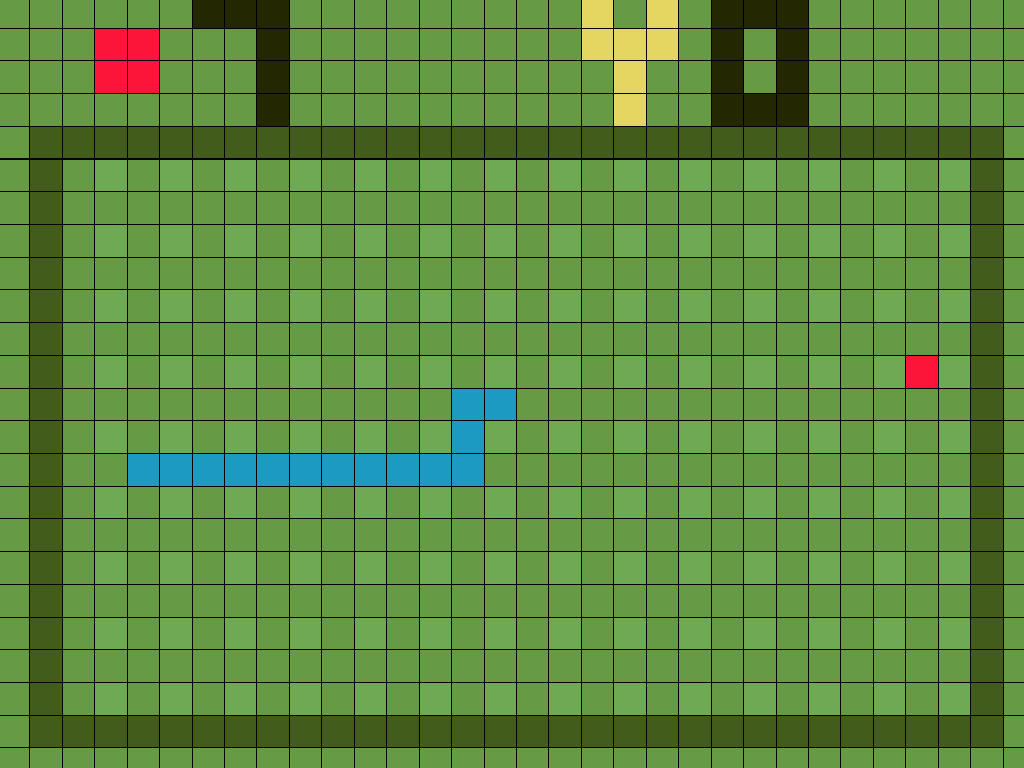
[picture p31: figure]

Mon deuxième jeu n’est plus tetris, comme prévu, mais snake j’ai donc aussi fait sa map.

Après avoir fini l’aspect graphique de mes deux jeux, je suis passé aux premières parties du code. Il fallait que je fasse une librairie de base, en effet le système de collision de mes deux jeux est le même. Donc j’ai commencé à réfléchir à la librairie de collision de mes jeux. J’ai choisi de représenter mes jeux sous forme d’une liste qui sera la liste de base. Ainsi pour modifier le positionnement il faudra changer l’indice de la liste. Me restant plus beaucoup de temps j’ai cherché les meilleurs moyens et comment créer une librairie sur arduino.

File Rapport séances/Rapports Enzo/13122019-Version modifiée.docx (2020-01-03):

Rapport de séance du 13/12/2019

- Téléchargement du logiciel Autodesk Inventor pour la modélisation du boitier de la Gameboy.

- Recherche des composants sur le site Ali express vu que j’avais cherché les composants sur Amazon.

- Recherche des différentes librairies nécessaire pour les composants du projet : librairie pour l’écran (UTFT et URTouch téléchargable uniquement à partir d’internet) , test des autres composants pour observer les données qu’ils envoient pour réfléchir aux programmes informatiques associés.

-Obtention des composants nécessaire à notre projet à partir d’un projet des années précédentes.

- Début de la modélisation du boitier : proposition de différents design pour l’aspect de la gameboy, pour finir d’accord sur un écran en position portrait et les boutons en dessous de l’écran ( joystick à gauche et les boutons d’action à droite). Modélisation de la face avant de la gameboy sans mesures précises pour nous donner un aperçu.

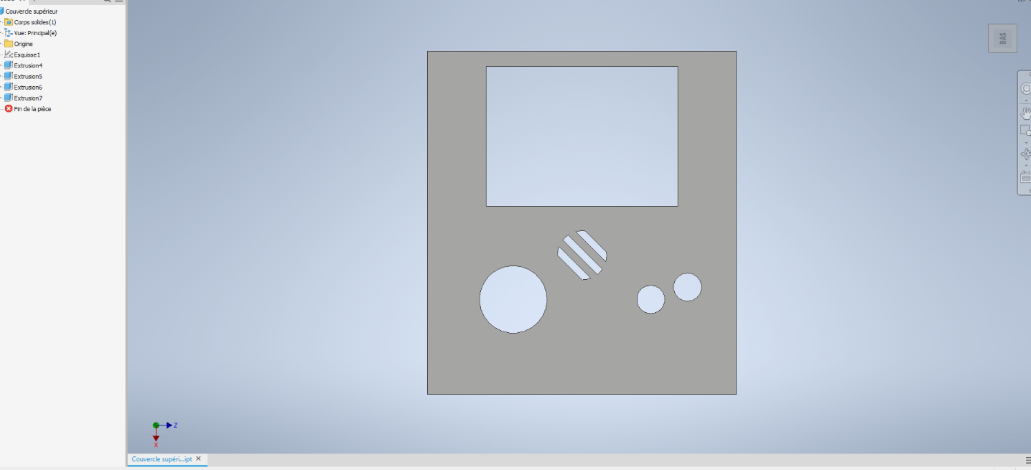
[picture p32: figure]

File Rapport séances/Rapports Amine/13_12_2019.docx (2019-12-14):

Rapport de Séance du 13 décembre 2019

- Vérification du github et des pièces

Nous avions pris nos pièces sur le site amazon, donc j’ai dû retrouver les liens sur ali express. Puis j’ai choisi le logiciel Autodesk inventor pour faire la modélisation 3d de nos pièces. En attendant son téléchargement je me suis intéressé au library arduino permettant de prendre en charge notre interface graphique. Il y’avait notamment Adafruit gfx, qui nous donne les fonctions de base (e.g dessin de trait, cercle).

- Modélisation

Notre plus grosse contrainte était l²’ergonomie de notre console (donc la boîte) qui contiendrait nos composants. J’ai essayé plusieurs conception 3d et nous avons hésité si nous utiliserons un affichage portait ou paysage. Chacun ayant ses inconvénients. L’idée nous est venue après plusieurs modélisation 3d, au liesu de partir sur un seul « corps », on partirait sur un modèle comme la 2ds, plat et dissociant la partie bouton (joystick, power off/on etc..) et l’écran.

Il nous a donc été conseillé d’utiliser la carte arduino due, qui est beaucoup plus puissante que la méga 2560. Le modèle ds était donc parfaitement adapté. Vient alors un problème supplémentaire, si l’on joue trop la carte va-t-elle se réchauffer ? Doit on donc installer un système de refroidissement (mini ventilo) etc.. Notre modélisation devient donc plus compliquée que prévu, et j’ai essayé de trouver des solutions le reste de la séance car dans notre planning nous avions prévu de la finir pour la prochaine séance…

- Les Pièces

C’est un retournement de situation positif en effet nous avons pu avoir toutes les pièces que nous cherchions, ainsi j’ai pu améliorer la précision de ma modélisation. Mais le joystick étant beaucoup plus « gros » que les boutons d’interactions, il a fallu repenser cette même modélisation affin d’équilibrer le tout. Il me manque donc à compléter ma modélisation avec les types de vis que nous allons utiliser pour notre boitier, le design de celui-ci, en effet le port de téléversement de la carte arduino doit rester très facilement accessible, en fin de séance la question du refroidissement par ventilation est restée en suspens

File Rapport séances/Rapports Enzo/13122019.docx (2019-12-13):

Rapport de séance du 13/12/2019

- Téléchargement du logiciel Autodesk Inventor pour la modélisation du boitier de la Gameboy

- Début de la modélisation du boitier

- Recherche des différentes librairies nécessaire pour les composants du projet

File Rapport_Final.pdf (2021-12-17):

## Département d’Electronique

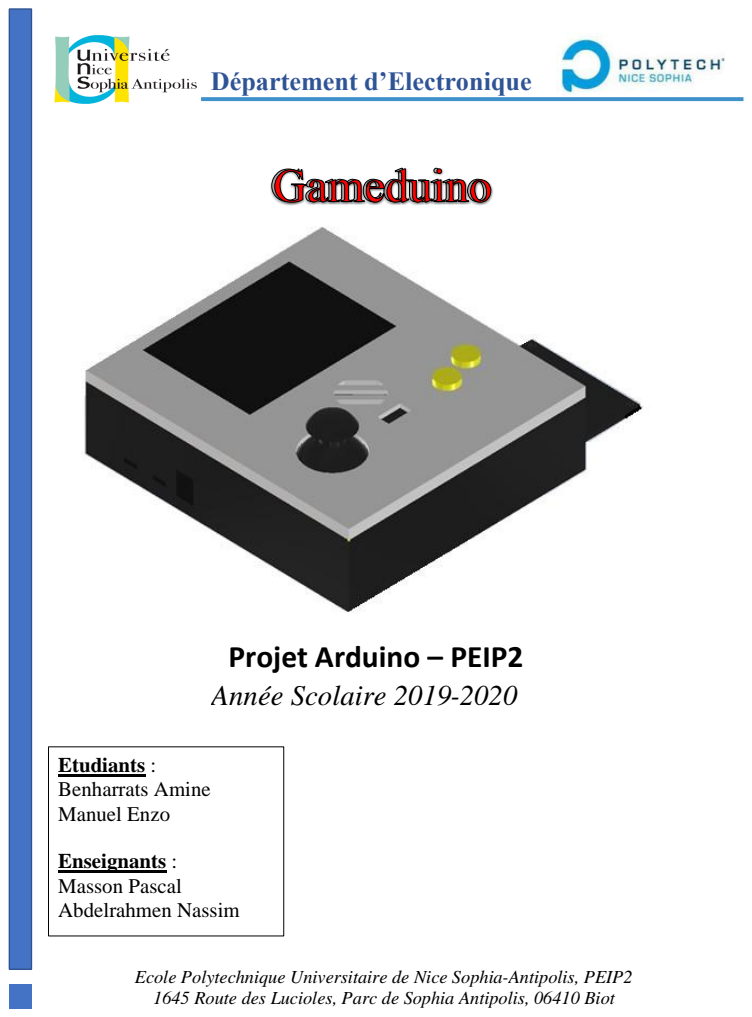
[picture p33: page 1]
Projet Arduino – PEIP2; Année Scolaire 2019-2020; Etudiants : Benharrats Amine Manuel Enzo; Enseignants : Masson Pascal Abdelrahmen Nassim

Ecole Polytechnique Universitaire de Nice Sophia-Antipolis, PEIP2
1645 Route des Lucioles, Parc de Sophia Antipolis, 06410 Biot

# SOMMAIRE

## Table des matières

I. Présentation du projet

Etant tout deux passionnés de jeux vidéo et de codage informatique, nous avons décidé de réunir nos

deux passions dans notre projet : la Gameduino. Cette dernière est une console portable de jeux vidéo.

Cette petite console vous permet de jouer à des jeux d’arcades tel que le Pong ou le Snake. Nous

verrons, dans une première partie, la réalisation du boitier et le montage. Puis dans une seconde partie

nous aborderons le code que nous avons réalisé pour l’électronique et celui concernant nos jeux.

II. Cahier des charges

Objectif : Créer une console de jeux vidéo compacte et portable avec deux jeux Pong et Snake

Découpage du projet :

Partie boitier :
- Design
- Modélisation
- Impression
- Montage

Partie code :
- Librairie utilisés
- Librairies codés
- Menu
- Pong
- Snake

## Liste du matériel utilisé :

Les principaux éléments utilisés sont (figure 1)

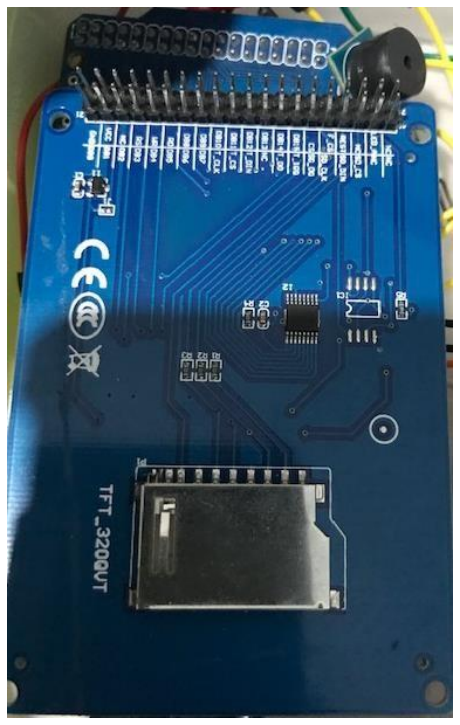
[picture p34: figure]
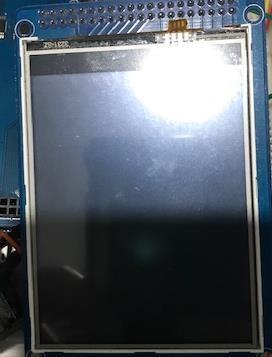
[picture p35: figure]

Carte Arduino Due | Adaptateur carte/écran 3,5’’ tactile
Joystick | 2 Boutons

## Figure 1 : matériel utilisé

Autres :

- 1 Buzzer
- Acide polylactique (plastique pour réaliser notre boîtier à l’aide de l’imprimante 3D)

III. Partie Boîtier

### 1. Design

Pour la réalisation de notre projet nous avons dû dans un premier temps nous mettre d’accord à deux

sur l’aspect final et l’esthétique que notre console aura (figure 2) : elle devait être ergonomique,

adaptée pour des jeux vidéo, elle devait être mobile et devait contenir tous les composants

électroniques.

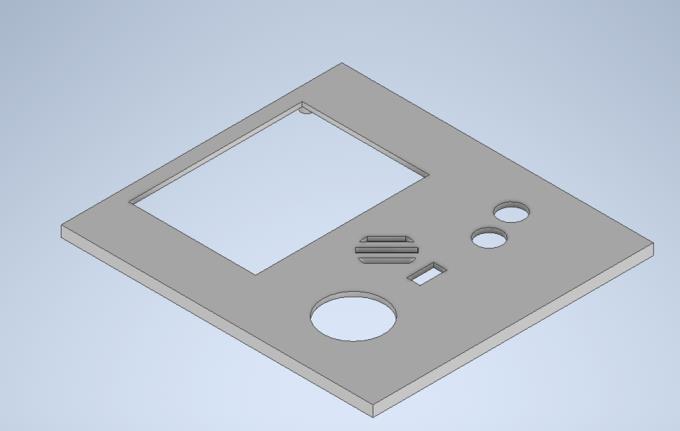
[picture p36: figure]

Figure 2 : Couvercle du boîtier supérieur

### 2. Modélisation

La contrainte de la taille de la console nous a posé un problème : Le boitier devait être le plus petit

possible pour être tenu dans les mains et que l’on puisse y jouer et il devait également contenir tous

les éléments qui composent notre console.

Pour éviter de se tromper dans la taille du boitier final de la console, nous avons modélisé la forme

extérieure de chaque composant (figure 3), en tenant compte de sa taille exacte avec Autodesk

Inventor. Une fois les pièces modélisées nous avons, toujours grâce à ce logiciel, simulé le montage

final des pièces à l’intérieur du boitier.

A partir de ce montage final, nous avions les dimensions exactes de notre boitier final ainsi que la

positions exactes des ouvertures pour les différentes pièces (joystick, boutons...).

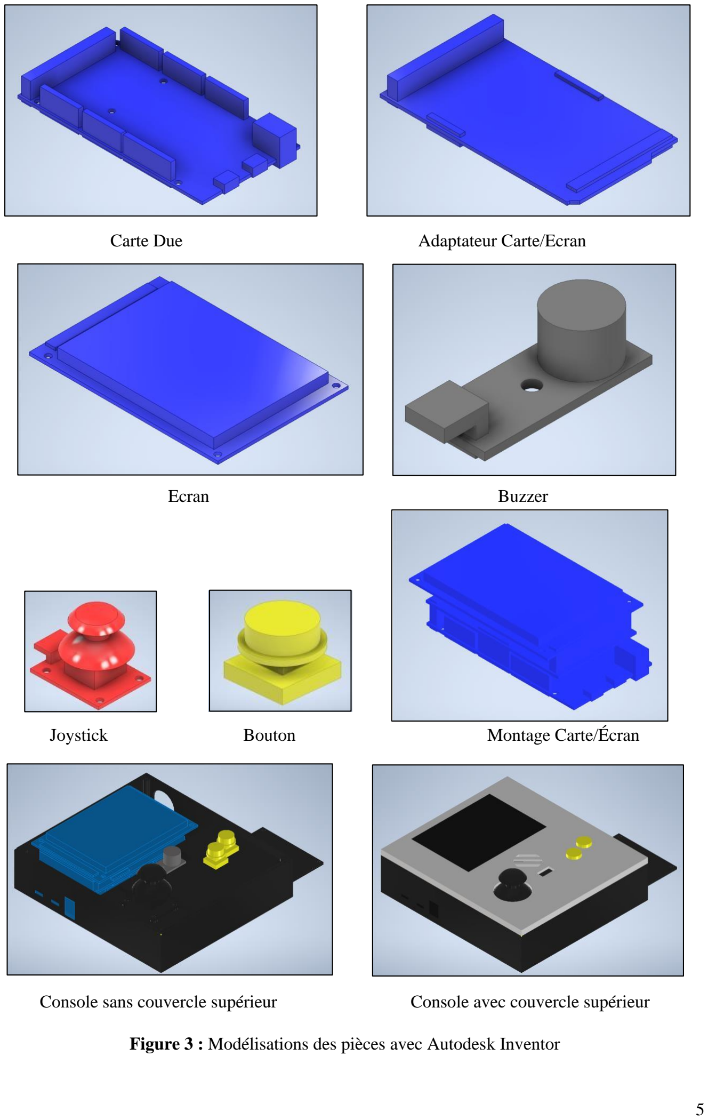
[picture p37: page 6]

Carte Due | Adaptateur Carte/Ecran
Joystick | Bouton | Montage Carte/Écran
Console sans couvercle supérieur | Console avec couvercle supérieur

Figure 3 : Modélisations des pièces avec Autodesk Inventor

Ecran | Buzzer

### 3. Impression

Pour imprimer, à l’aide d’une imprimante 3D, le boitier modélisé nous devions convertir nos

modélisations au format « stl ». Nous nous sommes rendu compte que ce format divisait les

dimensions par 10, le boitier final était de 1 cm par 2 cm. Nous avons donc adapté les bonnes

dimensions.

Après l’impression nous nous sommes rendu compte que l’imprimante avait une grande imprécision

au vu des détails que nous avions dans la modélisation : nous avions prévu des trous permettant de

faciliter l’insertion des vis, or ces derniers n’étaient pas imprimés. Les deux parties du boitier ne

s’emboîtaient pas parfaitement, nous avons dû les limer pour permettre leur emboitement. Ce

problème d’imprécision concernait également l’ouverture à l’emplacement de l’écran et des boutons.

Cette adaptation du modèle imprimé nous a pris énormément de temps.

### 4. Montage

Un fois le boitier adapté aux différents composants nous avons commencé le montage de ces éléments.

Nous avions décidé d’utiliser des vis pour les différentes fixations, ceci permettait d’assurer une

robustesse de l’ensemble et qui pouvait être facilement démontable si on le souhaitait pour changer

les composants par exemple. Pour se faire, nous avions prévu des supports munis d’un petit trou en

leur centre permettant de fixer nos composants avec des vis. Il s’est avéré que ces mêmes supports

n’étaient pas assez résistants pour supporter le simple fait de visser dessus. Nous avons alors

abandonné les vis comme mode d’assemblage.

Sur les conseils de notre professeur, Monsieur Masson, nous avons opté pour une fixation à l’aide de

la colle à l’aide d’un pistolet à colle. Nous avons donc collé nos éléments, sauf la carte qui posait un

problème quant à la fixation avec la colle, nous l’avons donc fixée avec du scratch.

Pour finir nous nous sommes penchés sur les câblages. Nous étions partis au préalable avec l’idée de

ne faire que des soudures mais après quelques essaies nous nous sommes rendu compte que la solidité

de nos soudures n’était pas suffisante, nous avons donc utilisé à la place des câbles mâle/femelle ce

qui nous a permis de réaliser un câblage relativement propre et solide.

Nous avons malgré tout dû souder certains composants comme les résistances avec les boutons. Une

fois avoir vérifié que tous les composants pouvaient bel et bien fonctionner à plusieurs reprises, nous

avons celé le boîtier avec à nouveau le pistolet à colle.

IV. Partie code

### 1. Librairie utilisée

Pour notre projet nous avons dû utiliser une seule librairie à savoir la librairie UTFT qui nous donne

accès aux fonctions de base nous permettant de contrôler notre écran, dessiner des fonctions de base

tel que des ronds, des rectangles, redéfinir la couleur du fond, effacer l’écran, etc...

### 2. Librairies programmées

Nous avons dû programmer nos propres librairies afin d’utiliser nos boutons et notre jostick. Ces

fonctions, permettent de nous envoyer des données facilement exploitables par nos jeux. Pour notre

joystick, la libraire nous permet d’obtenir son état pour :

- l’orientation horizontale
- l’orientation vertical
- le click du joystick, savoir s’il est pressé ou non.

Pour nos boutons, la librairie permet d’obtenir son état, s’il est pressé ou non.

Cependant nous avons rencontré un problème que nous n’avons pas réellement résolu : les entrées

digitales avec lesquels nous lisions l’état des boutons nous renvoyaient des valeurs non cohérentes

par rapport à notre circuit, nous nous sommes dit que c’était probablement dû au fait que nous avions

branché beaucoup de composant sur la carte simultanément, nous avons donc vérifié l’état des

boutons à partir des entrées analogiques qui nous donnaient des résultats qui étaient également

absurdes, mais qui expliquaient les résultats des entrées digitales : sans câble branché sur ces entrées,

le courant variait « naturellement » entre 2,5V et 3V. Les entrées analogiques nous permettaient donc

une certaine flexibilité pour pouvoir avoir des données exploitables, cependant une variation de

tension affecte le fonctionnement du programme, en effet lors de la démonstration lors de notre

présentation, l’entrée analogique du bouton B (droit) dépassait les 4.88V, seuil au-delà duquel nous

estimions que notre bouton était pressé, alors que nous n’appuyons pas dessus.

### 3. Pong


Figure 4

Le pong est un jeu d’arcade (Figure 4) , le but du jeu est simple, nous sommes le joueur à gauche de

l’écran et notre but est de renvoyer la balle à l’adversaire jusqu’à ce qu’il échoue en se déplaçant

verticalement. Ce jeu à été codé par Manuel Enzo.

Pour réaliser le jeu j’ai donc réalisé au préalable une liste des différentes variables et fonctions

qu’allait devoir comporter le jeu. A l’aide cette liste, j’ai réalisé différentes classes :

- la classe balle qui permet de gérer son déplacement, sa vitesse, son orientation(angle) et son

affichage.

- la classe paddle qui permet de gérer son déplacement, sa vitesse et son affichage.
- et enfin la classe pong qui regroupe le coeur du jeu, à savoir : le déroulement de la partie, l’affichage

de la carte générale du jeu, le fonctionnement de l’ia (joueur ordinateur à droite), les collisions, le

changement des scores,et la fin de partie.

La réalisation de ces classes m’a permis de facilité le codage du jeu par la suite, pour m’y retrouver

plus facilement.

Voici le diagramme du fonctionnement du jeu (la fonction startGame de la classe pong) : (Figure 5)

### 4. Snake

Le but de ce jeu est assez simple. Nourrir votre serpent pour le faire grandir en évitant les collisions

avec lui-même et l’environnement (dans mon jeu et dans la grande majorité des Snake,

l’environnement se limite aux murs ou à lui même). Ce jeu a été codé par Benharrats Amine.

Pour ce jeu j’ai utilisé un type de variable personnalisé : les structures. C’est-à-dire que tous les objets

de mon jeu (« gameItem ») auront les types définis dans la structure ici une position « X » et une

position « Y ».

Il y’a donc deux types d’objets la nourriture (« snakeFood ») et le serpent en lui-même (« snake »).

J’ai défini la taille des objets dans une variable et la longueur de départ du serpent. J’ai utilisé d’autres

variables pour, notamment, la direction etc..

J’ai aussi utilisé différentes fonctions pour :

- dessiner le serpent,
- dessiner la nourriture,
- gérer les collisions
- les entrées et changer les valeurs du serpent (pour le faire avancer ou grandir).

Comme on peut le voir avec le diagramme de fonctionnement (Figure 6) du jeu il me manquait

un élément majeur à ma partie programmation qui faisait que le jeu « buggait », c’était la gestion

des états du jeu. J’avais au début essayé et avait créé des variables « enum » avec les différents

états du jeu pour la fonctionnalité des « switch/break » pour changer ses états. Cela provoquant

plus de bug. Finalement le jeu gérait les collisions (sauf avec lui-même), les déplacements,

l’agrandissement du serpent mais à chaque boucle recréait toute la nourriture et réinitialiser les

coordonnées des collisions (c’est pour cela qu’on pouvait indéfiniment tourner sur nous-même).

Ainsi même si mon jeu n’a pas eu toutes les fonctionnalités, prévues initialement, j’ai pris un grand plaisir à le coder et découvrir un nouveau langage.

V. Conclusion

Pour conclure, malgré les difficultés rencontrées lors de la réalisation de notre projet, ce dernier rempli

la plupart des objectifs fixés, la console est compacte et permet de jouer à des jeux d’arcades. Il reste

cependant des améliorations possibles, comme changer le composant d’alimentation de pile pour

rendre la Gameduino autonome sans la nécessité de la relier à un câble électrique. Nous pouvons

également améliorer les différents jeux existants et en rajouter d’autres.

VI. Bibliographie

https://letmeknow.fr/blog/2013/11/07/tuto- (https://eur05.safelinks.protection.outlook.com/?reserved=0)utiliser- (https://eur05.safelinks.protection.outlook.com/?reserved=0)un- (https://eur05.safelinks.protection.outlook.com/?reserved=0)j (https://eur05.safelinks.protection.outlook.com/?reserved=0)oystick- (https://eur05.safelinks.protection.outlook.com/?reserved=0)2- (https://eur05.safelinks.protection.outlook.com/?reserved=0)axes/ (https://eur05.safelinks.protection.outlook.com/?reserved=0)

https://www.arduino.cc/en/Guide/ArduinoDue

https://www.arduino.cc/en/Hacking/PinMappingSAM3X

http://wiki.sainsmart.com/index.php/3.2%22_TFT_Touch_LCD

http://www.rinkydinkelectronics.com/library.php?id=87

Arduino - (https://eur05.safelinks.protection.outlook.com/?reserved=0) ArduinoDue (https://eur05.safelinks.protection.outlook.com/?reserved=0) Open-source electronic prototyping platform enabling users to create interactive electronic objects.

Arduino - (https://eur05.safelinks.protection.outlook.com/?reserved=0) PinMappingSAM3X (https://eur05.safelinks.protection.outlook.com/?reserved=0)
Open-source electronic prototyping platform enabling users to create interactive electronic objects.

3.2%22_TFT_Touch_LCD (https://eur05.safelinks.protection.outlook.com/?reserved=0)

VII. Index

## Figure 5


Figure 6


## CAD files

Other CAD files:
Modélisation/Adaptateur écran_carte.ipt
Modélisation/Assemblage carte_ecran.iam
Modélisation/Bouton.ipt
Modélisation/Buzzer.ipt
Modélisation/Carte Due.ipt
Modélisation/Couvercle inférieur.ipt
Modélisation/Couvercle supérieur.ipt
Modélisation/Ecran.ipt
Modélisation/Joystick.ipt
Modélisation/assembage générale.iam

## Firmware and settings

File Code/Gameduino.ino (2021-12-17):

#include <UTFT.h>
#include <button.h>
#include <joystick.h>
#include <pong.h>
#include <ball.h>
#include <paddle.h>

UTFT myGLCD(ITDB32S,38,39,40,41);

joystick joystick(56,54,55);

button A(58);
button B(59);

extern uint8_t BigFont[];

const int BUZZER = 8;

int menu_location = 1;

void setup(){
  Serial.begin(9600);
  pinMode(BUZZER,OUTPUT);
  myGLCD.InitLCD();
  myGLCD.setFont(BigFont);
  myGLCD.clrScr();
}

void loop(){
  myGLCD.setColor(255,255,255);
  myGLCD.print("Gameduino",100,10);
  if(menu_location == 1){
    myGLCD.setColor(255,0,0);
    myGLCD.print("PONG",50,110);
    myGLCD.drawRect(10,40,149,199);
    myGLCD.setColor(255,255,255);
    myGLCD.print("SNAKE",200,110);
    myGLCD.drawRect(169,40,309,199);
   }
  else if(menu_location == -1){
    myGLCD.setColor(255,255,255);
    myGLCD.print("PONG",50,110);
    myGLCD.drawRect(10,40,149,199);
    myGLCD.setColor(255,0,0);
    myGLCD.print("SNAKE",200,110);
    myGLCD.drawRect(169,40,309,199);
  }
  if(B.IsPressed()){
    menu_location = -1*menu_location;
    delay(250);
  }
  if(A.IsPressed()){
    if(menu_location == 1){
      pong pong(myGLCD);
      pong.startGame(joystick);}
    else{
      while(true){
      myGLCD.clrScr();
      myGLCD.setColor(255, 0, 0);
      playGame();}
      }
  }
}

int snakeDir=1;

struct gameItem{
  int X;
  int Y;
};

String horizontal;
String vertical;

int gameItemSize=4;
unsigned int snakeSize=5;

gameItem snake[100];
gameItem snakeFood;

void draw(){
  drawSnake();
  drawFood();
}

void drawSnake(){
  for(int i=0;i<snakeSize;i++){
    myGLCD.drawRect(snake[i].X,snake[i].Y,snake[i].X+5,snake[i].Y+5);
  }
}

void drawFood(){
    snakeFood.X=random(2,320);
    snakeFood.Y=random(2,240);
    myGLCD.fillCircle(snakeFood.X,snakeFood.Y,4);
 
    }
    
void handleColisions(){
  if(snake[0].X==snakeFood.X && snake[0].Y == snakeFood.Y) {
    snakeSize++;
    drawFood();    
  }
else {
    for (int i = 1; i < snakeSize; i++) {
      if (snake[0].X == snake[i].X && snake[0].Y == snake[i].Y) {
          myGLCD.clrScr();
          myGLCD.setColor(255, 0, 0);
          delay(50);
      }
    }
  }

  if ((snake[0].X < 1) || (snake[0].Y < 1) || (snake[0].X > 320) || (snake[0].Y > 240)) {
    myGLCD.clrScr();
    myGLCD.setColor(255, 0, 0);
    delay(50);
  }
}

void handleInput(){
  if(joystick.horizontalDirection()=="left" && snakeDir !=1){
    snakeDir=0;
  }
  if(joystick.horizontalDirection()=="right" && snakeDir!=0){
    snakeDir=1;
  }
  if( joystick.verticalDirection()=="forward" && snakeDir!=3){
    snakeDir=2;
  }
  if( joystick.verticalDirection()=="backward" && snakeDir!=2){
    snakeDir=3;
  }
}

void updateValues() {
 
  for (int i = snakeSize - 1; i > 0; i--) {
    snake[i] = snake[i - 1];
  }

  
  //gauche
  if (snakeDir == 0) {

    snake[0].X -= gameItemSize;
  }
  //droite
  else if (snakeDir == 1) {

    snake[0].X += gameItemSize;
  }

  //bas
  else if (snakeDir == 3) {

    snake[0].Y += gameItemSize;
  }

  //haut
  else if (snakeDir == 2) {

    snake[0].Y -= gameItemSize;
  }

}

void playGame() {
  handleColisions();
  handleInput();
  updateValues();
  
  draw();
  delay(50);
}

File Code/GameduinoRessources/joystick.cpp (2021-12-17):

/*
 * joystick.cpp
 *
 *  Created on: 2 mars 2020
 *      Author: Manuel Enzo
 */

#include "Arduino.h"
#include "joystick.h"

joystick::joystick(int aB, int aX, int aY) {
	analogPortButton = aB;
	analogPortXAxis = aY;
	analogPortYAxis = aX;
}

String joystick::horizontalDirection(){
	String right("right");
	String left("left");
	String none("none");
	
	if(analogRead(analogPortXAxis)>1000){
		return left;
	}
	if(analogRead(analogPortXAxis)<200){
		return right;
	}
	return none;
}

String joystick::verticalDirection(){
	String forward("forward");
	String backward("backward");
	String none("none");
	
	if(analogRead(analogPortYAxis)>1000){
		return backward;
	}
	if(analogRead(analogPortYAxis)<100){
		return forward;
		}
	return none;
}
bool joystick::IsPressed(){
	if(analogRead(analogPortButton)<100){
			return true;
		}
	return false;
}
